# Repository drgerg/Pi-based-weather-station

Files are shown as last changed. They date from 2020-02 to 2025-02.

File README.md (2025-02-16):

# The Quest for a Reliable, Robust, Repairable Raspberry Pi-based Weather Station

**February, 2025 NOTE**: Over five years later, this weather station is still plugging away. There are occasional failures, but they are fixable.  That was the whole point.  I am **very** satisfied with this station as well as the home-brew front end I use to interact with it. It does exactly what it was designed to do. What more is there to say.

July 11, 2021 NOTE: I added a program flow-chart to the Station_Assembly_Docs folder that gives an overview of how the code parts fit together.

I just installed a DHT22 temperature and humidity sensor in WeatherPi. This sensor is more accurate than the BME280, apparently.  My experience so far proves this out.  I'm using the atmospheric pressure reading from the BME280, but now the temperature and humidity readings are coming from the DHT22.  The updated code is posted here today.

I was very pleased to see how well all the pieces and parts of WeatherPi are holding up.  Life outdoors can be brutal, but this little guy is doing well.

November 28, 2020 NOTE: The WeatherPi made it through Hurricane Sally and the rest of the hurricane season just fine.  It recorded over two feet of rainfall, and winds in excess of 75mph before the power went out and the battery eventually died.  I am very proud of the performance of the system and tickled pink that what has become the Pi-Net works so well.

Sept. 14, 2020 NOTE: The YuHan power supply died during a lightening storm.  I replaced it with the guts from a dead inexpensive UPS and a 120VAC to 12VDC supply. I replaced the UPS's dead battery with a fresh 5AH battery (which was twice the size of the original.)  If you're interested in this build, keep this in mind.  I'll get those details updated here as soon as I can. (new photos in PICS folder)

Project Initialized October 2019.
Project opened to public on Github February 2020. As built: c.$470.00.
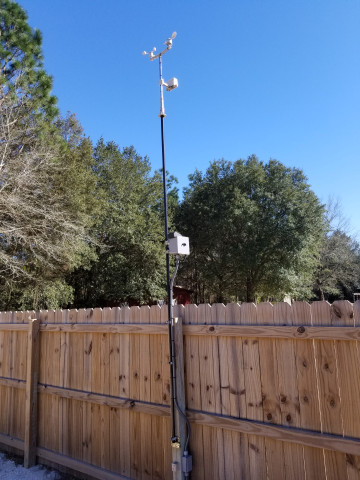
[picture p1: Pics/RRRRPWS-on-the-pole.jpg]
RRRRPWS on the pole.
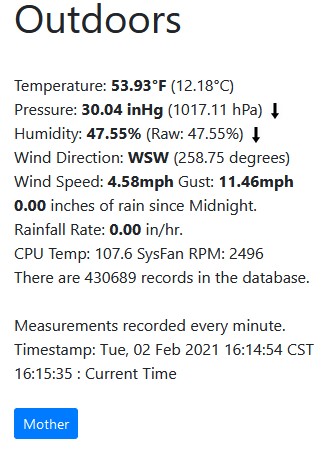
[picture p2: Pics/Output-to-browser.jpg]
Output as seen in browser.
  

My station is up and running.  It works.  I get good, accurate, stable readings for temperature, pressure, humidity, wind speed, wind direction and rainfall. I interact with my system by means of a web browser on my desktop or phone.

This project is not an easy one, but if I can build it, so can other people.

Here's what's where:

- **Code**: contains the Python3 code in the 'out' folder as well as the 'all' folder, which contains code for the mySQL server and browser front-end.  This folder also contains 'The_Code_is_what_it_is.md' which provides more detail on all that.
- **Component_Docs**: contains collected documentation for the various hardware pieces of the station.  The Station_Parts_List.pdf is there.
- **Pics**: contains pictures of the pieces and parts (640x480).  Contact me if you want higher resolution pics.
- **SKP_STL**: contains the Sketchup and stereolithography files for the 3D printed parts I designed for this project.
- **Station_Assembly_Docs**: contains documents pertaining to the actual assembly of the station.
  - **There are no step-by-step instructions there.**  But there is a [block diagram](./Station_Assembly_Docs/System_Block_Diagram.pdf) and a [schematic diagram](./Station_Assembly_Docs/WeatherPi_System_Schematic-V1.3.pdf).  And don't forget the Station_Parts_List.pdf in Component Docs.

This is not a quick-and-easy project.  The station is powered by a remote 12VDC power supply with a battery backup.  I dug a trench, put PVC conduit in it, and pulled 14AWG Romex into it.  It's a good solution.  I drove ground rods and put in-line lighting/surge protectors on both ends of that power run.  I use the guts from a low-cost UPS feeding a Buck converter for power.  By routing the 12V output of the converter through a relay (which is triggered by the PoolPi), I have a way to remotely power-cycle (reboot) the station.  This was VERY handy during development.

The whole Weather Station package is really two computers (and interfaces with two more the way I have it set up here).  The station acquires data from the sensors, makes necessary calculations and stores that data via WiFi to a mySQL server running in my house.  That machine also serves web interface data to end-users using Python/Flask/Jinja/Gunicorn and nginx (webserver).  Video from the Pi Camera gets sent to my Zoneminder system. That video **can** be viewed directly from the station using a web browser, but I already had Zoneminder going, so it just made sense to incorporate the feed from the WeatherPi.  The front-end server ("all" is its name) also displays the temperature and humidity in my shop.  That is gathered by another Pi with a DTH11 sensor on it.  It also writes to the mySQL database.

No guarantees are made. None. That is normal in projects such as this.

I have a pretty complete parts list and the aforementioned block diagram and wiring schematic available in the repo here.

### A bit of History

After throwing away my second Acurite weather station in only two years I decided I would build my own.  It may be cheaper to buy a more expensive commercial brand like Davis, but honestly, I'm sick of the throw-away culture when I can do something about it.

The goal of this project is to take advantage of the availability of the modular Pi and Arduino sensors and boards to create a weather station that I could repair when something died.  The Pi lives on the pole with the sensors, and communicates over WiFi.

The project is written in Python 3.

I don't try to make this system available to the Internet.  It is intended to be viewed and used locally, or by means of a VPN. I do upload data to [PWSWeather.com](https://www.pwsweather.com/station/pws/kflmilto35), which works really well.

I am making every attempt to provide enough documentation and schematics for anyone else to duplicate what I've done.

I am a self-taught coder, as anyone with experience can plainly see.  What I know is what I've done so far works here, and provides me with reliable and accurate data as compared to all the local commercial and government data sources.  

I use Visual Studio Code in Windows.  I use Microsoft's Remote-SSH extensions to work with my code on the WeatherPi out on the pole in the backyard.  The WeatherPi stores its data in a mySQL database running on another machine in the house. I use Filezilla to keep local copies of my code when I'm done editing and testing.

The system runs on a Pi 4 Model B.  Rather than re-invent the wheel on environmental sensors, I bought [Sparkfun's SEN-08942 Weather Meters](https://www.sparkfun.com/products/8942). I have a [DROK buck-converter](./Pics/DROK-Buck-Converter-mount.jpg) DC-to-DC power board, a real-time clock module, a analog-to-digital module, and a BME280 temperature, pressure, humidity sensor module all living in the box on the pole.  A Pi Camera v2 provides a 1280x720 view of the outdoor conditions.  

I own a Prusa MK3S 3D printer which I use to make mounts and other custom parts for assembling the whole thing.  Unlike many people who seem to think you can't use Sketchup for modeling for printing, I do it all the time with no problem.  The .skp and .stl files are here for you to use as you see fit.

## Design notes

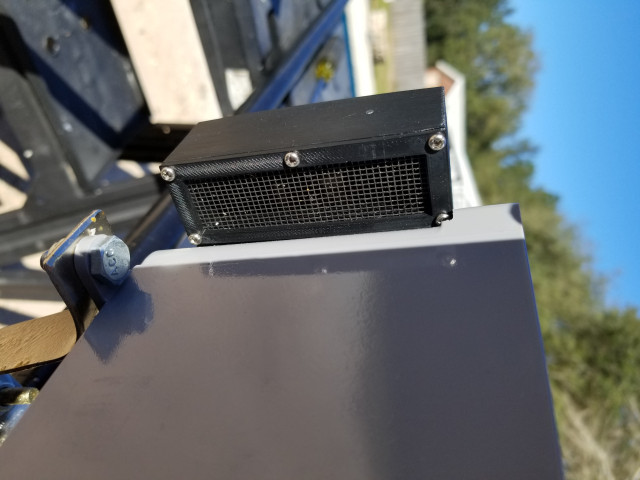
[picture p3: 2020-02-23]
Pics/air-chimney-output-vent.jpg

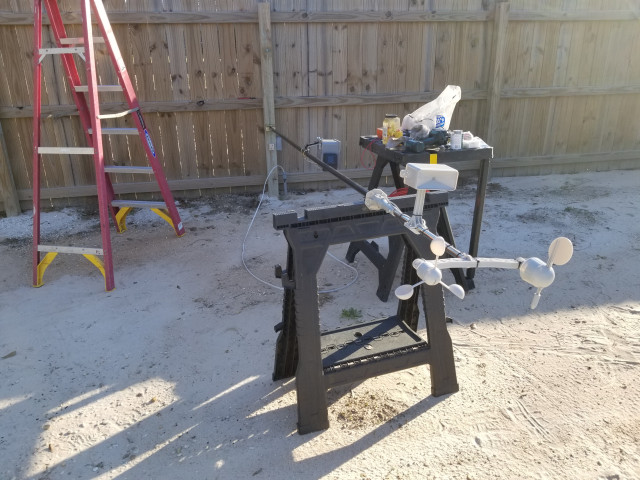
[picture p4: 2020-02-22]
Pics/RRRRPWS-service-mode.jpg

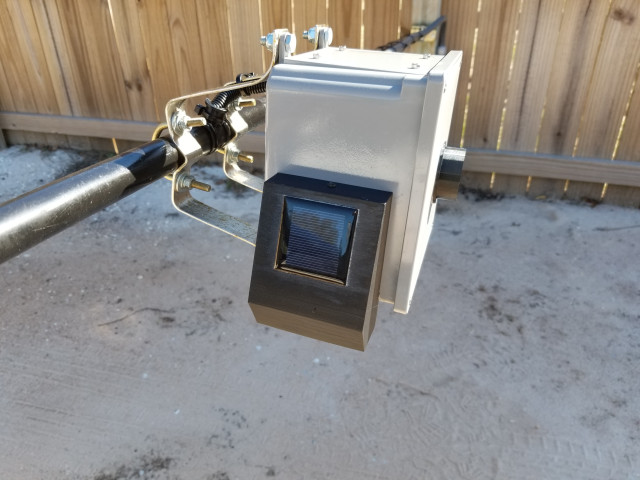
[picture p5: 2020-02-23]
Pics/RRRRPWS-top-view.jpg

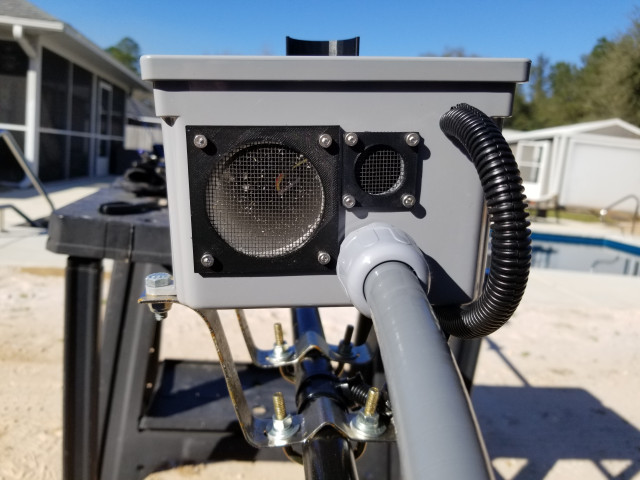
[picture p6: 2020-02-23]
Pics/RRRRPWS-bottom-view.jpg

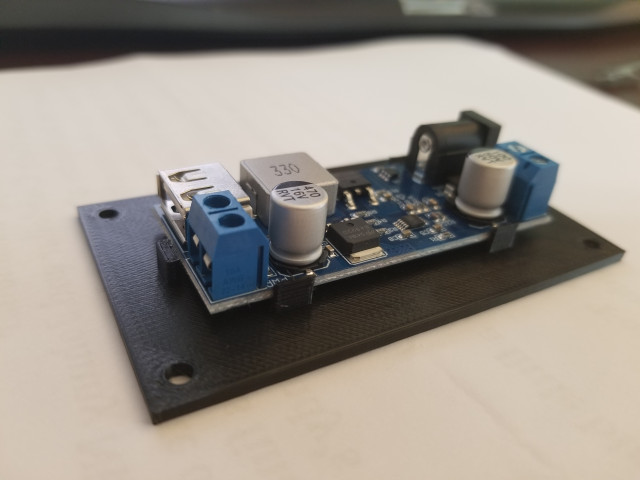
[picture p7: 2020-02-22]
Pics/DROK-Buck-Converter-mount.jpg

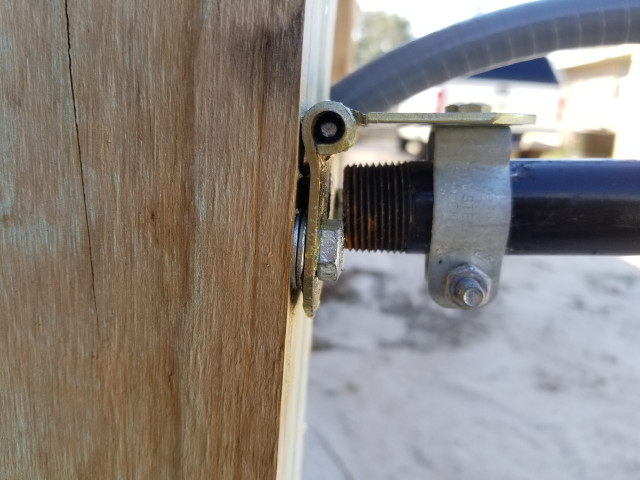
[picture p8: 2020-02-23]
Pics/bottom-mount-hinge.jpg

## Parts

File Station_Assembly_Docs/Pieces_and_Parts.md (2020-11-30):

# Pieces and Parts: Things you can get that make life easier

Getting the hardware part of this project together is not a trivial task.  I am hoping after a year of use I will be able to say it was worth it. (That's how long each of the two Accurite stations lasted.  Pathetic.)

**Be sure to look at the Station_Parts_List.pdf** located in the Component_Docs folder.  That's where I list the major parts that make up the weather station.

I have a carefully curated collection of odd things that make all of this easier.  I'm happy to share the list with you.  Most of it comes from Amazon.

* [EDGELEC 120pcs Breadboard Jumper Wires](https://www.amazon.com/gp/product/B07GD2BWPY/ref=ppx_yo_dt_b_asin_title_o05_s01?ie=UTF8&th=1) - These are made from copper wire, unlike some which are made from copper-coated aluminum.  If you ever need to clip off one end and solder it onto something (like I do frequently), you will be glad you got all copper.
* [Litorange 320PCS M2 Male Female Nylon Hex Spacer Standoff Screw Nut Assorted Assortment Kit (Black) ](https://www.amazon.com/gp/product/B07D78PFQL/ref=ppx_yo_dt_b_asin_title_o00_s00?ie=UTF8&psc=1) - I have two sizes of these standoffs, and they are wonderful.  Both of the kits I have contain multiple lengths of standoffs, screws, washers and nuts.  All nylon, and amazingly strong.
* [12v to 5v 5A Converter, DROK USB Buck Converter Voltage Regulator DC 9V-36V Step Down to DC 5V-5.3V 3.5-6A Volt Transformer Power Supply Module ](https://www.amazon.com/gp/product/B01NALDSJ0/ref=ppx_yo_dt_b_asin_title_o00_s00?ie=UTF8&psc=1) - I have about 5 of these guys now.  They are rock-solid and versatile.  They make me happy.
* [HVAZI 320pcs M2.5 Nylon Hex Spacer Standoffs Screws Nuts Assortment Kit; Male-Female(Black) ](https://www.amazon.com/gp/product/B06XKWDSPT/ref=ppx_yo_dt_b_asin_title_o03_s00?ie=UTF8&psc=1) - The other standoff kit.
* [18-8 Stainless Steel Flat Washer, Plain Finish, Meets DIN 9021, M3 Hole Size, 3.2mm ID, 9mm OD, 0.8mm Nominal Thickness (Pack of 100) ](https://www.amazon.com/gp/product/B009OK7GPO/ref=ppx_yo_dt_b_asin_title_o00_s00?ie=UTF8&psc=1) - Stainless Steel flat washers.  Part of the collection of Stainless Steel fasteners that I can't live without.
* [Honbay 100pcs 304 Stainless Steel M3 Square Nuts](https://www.amazon.com/gp/product/B06XPFLNBS/ref=ppx_yo_dt_b_asin_title_o08_s00?ie=UTF8&psc=1) - I learned the value of these square nuts when I assembled my Prusa MK3S kit.  More Stainless Steel fasteners.
* [iExcell 600 Pcs Metric M3 DIN912 Stainless Steel 304 Hex Socket Head Cap Screws Nuts Washers Hex Key Wrench Kit ](https://www.amazon.com/gp/product/B07J44YXV3/ref=ppx_yo_dt_b_asin_title_o08_s00?ie=UTF8&psc=1) - I use these a LOT for projects that have Arduino or Raspberry Pi parts.  The 3mm screws are used more on my custom mounts than anything else.  More of the Stainless Steel fastener collection.
* [HVAZI Metric M2.5 304 Stainless Steel Button Head Socket Cap Screws Nuts Assortment Kit](https://www.amazon.com/gp/product/B076ZN18KZ/ref=ppx_yo_dt_b_asin_title_o08_s00?ie=UTF8&psc=1) - The Raspberry Pi has mounting hole in its PCB that accept these 2.5mm screws.  More of the Stainless Steel fastener collection.
* [CHENBO 620pcs 2.54mm/0.1" Connectors Wire Jumper Cable Pin Header Connector Crimp Pins Kit](https://www.amazon.com/gp/product/B077X8XV2J/ref=ppx_yo_dt_b_asin_title_o03_s00?ie=UTF8&psc=1) - Pins, Sockets, and plastic connector bodies of various pin-counts.  Use the tool below to crimp these pins.
* [IWISS Open Barrel Terminal Crimper Plier Tool for Molex Style DELPHI AMP TYCO Terminals Crimper Open Barrel 24-14 AWG](https://www.amazon.com/gp/product/B07476C1LD/ref=ppx_yo_dt_b_asin_title_o04_s00?ie=UTF8&psc=1) - This is a pretty good tool. What I mean by that is, you can crimp Molex and other open-barrel pins with it, including DuPont pins and sockets, which is what we use with the Pi and such. The tool works adequately, and is cheap. A better quality tool like this is way more expensive. You will have to learn how to get good results with this (or any) tool. It is not intuitive, but it can be done, and once done, it's as good as a million dollar crimp.
* [IWISS SN-28B Crimping Tool for AWG28-18 Dupont Pins](https://www.amazon.com/IWISS-Professional-Compression-Ratcheting-Wire-electrode/dp/B00OMM4YUY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) - This is a tool I just discovered that is not very expensive and will deliver a better quality crimp.  I say that based on decades of crimping all sorts of connectors.  I may be buying this tool for my own bench.

I listed these parts because having a stock of this stuff saves me a lot of time and results in a finished product that works well and one I'm not ashamed to show people.  If you can afford to do so, I highly recommend you stock your hobby locker with these sorts of parts and pieces.

* [5VDC 4-wire cooling fan](https://www.amazon.com/BSB05505HP-BASA5508R5H-0-40A-5-5-Cooling/dp/B01JEDTE5K) - The cooling fan I used was one I had scavenged from a dead laptop.  As of 4/28/20 this fan, which is similar but not exactly the same, is available for $14 at Amazon. It is a replacement fan for a Lenovo NUC or laptop.  I'm putting this in here just to give anyone who cares a place to start.

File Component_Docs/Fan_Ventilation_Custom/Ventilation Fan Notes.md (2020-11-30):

### Ventilation Fan Notes

There is an occasional need for additional ventilation other than that provided by natural convection.

I used a small 5V fan I had scavenged from a laptop some years ago.  It is a 4-wire fan, which means it has a speed sensor, and can be controlled by a PWM output on the Pi.

This [replacement fan from Amazon](https://www.amazon.com/Tested-Replacement-Cooling-Inspiron-CN-031TPT/dp/B07J4LFRYX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) should be a drop-in replacement for the fan I used. 

I printed custom mounting parts for this fan.  This means anyone else building this project will need to figure out how they're going to mount whatever fan they have to use for this particular application.

I could not find any documentation for the specific fan I had, but I did find a similar fan by the same manufacturer and have included the spec sheet on it here.

The sketch in the .jpg file comes from a YouTube video and was helpful in sorting out how to use the 4-wire fan in my project.

The final working wiring diagram is incorporated into the main schematic for the station.

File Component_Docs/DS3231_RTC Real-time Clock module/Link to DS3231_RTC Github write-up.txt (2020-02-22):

http://www.intellamech.com/RaspberryPi-projects/rpi_RTCds3231

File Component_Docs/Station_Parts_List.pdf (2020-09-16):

Printed for Ledger paper | 11"x17" Landscape | Gregory A. Sanders, 2020
| | (#) means see Notes below | | | | | | $463.11
Category | Name | Purpose | Description | Make | Model | Qty | Cost | Extended | Vendor | SubstitutionOK?
Mounting | Pole | Main mount pole | LDR 3/4-in x 10-ft 150-PSI Black Iron Pipe | LDR | 314 34X120 | 1 | 20.79 | 20.79 | Lowes | yes
Mounting | Clamps - pole | hold pole to post | Sigma Electric ProConnex 3/4-in Conduit Hangers | Sigma | 49110 | 3 | 0.68 | 2.04 | Lowes | yes
Mounting | Paint | paint for black iron pole | Rust-Oleum Stops Rust Gloss Black Spray Paint | Rust-Oleum | 295387 | 1 | 3.97 | 3.97 | Lowes | yes, carefully
Mounting | Naptha (Paint Cleaner/thinner) | to clean black pipe for painting | Jasco 32-fl oz Fast to Dissolve Naphtha | Jasco | QJVM194 | 1 | 8.98 | 8.98 | Lowes | Naptha is best. Mineral spirits will do, but . . .
Mounting | PVC segment | transition from sensors to pipe (1) | See Note 1 | | | | | 0.00
Mounting | Hinge | allows pole to tilt down for service | Gatehouse 3-1/2-in Satin Nickel 5/8-in Radius Mortise Door Hinge | Gatehouse | S841-509 | 1 | 3.08 | 3.08 | Lowes | yes. any door hinge will be fine.
Mounting | Brackets | holds box on pole | RCA VH125R 4" Antenna Wall Mount Kit, 2 pk | RCA | VH125R | 1 | 5.98 | 5.98 | Lowes | yes, if distance between holes matches box
Housing | Box | Houses electrical components | 6 in. x 6 in. x 4 in. Gray PVC Junction Box | Carlon | E987RR | 1 | 13.94 | 13.94 | Home Depot | yes, but must be “weatherproof”
Housing | Box | houses pole-end lightning arrestor | 1-Gang Non-Metallic Weatherproof Gray Box with Three 1/2 in. or 3/4 in. Outlets Bell | | PSB37550GYB | 1 | 5.87 | 5.87 | Home Depot | yes, but must be “weatherproof”
Housing | Box | houses 120VAC to 12VDC supply | Electronic Equipment Enclosure Box, 12" x 12" x 4", Non-Metallic, 1-Pack | | EB1212-1 | 1 | 30.33 | 30.33 | Amazon | yes
Electrical | Liquid-tight conduit (2) | Conduit | Southwire Ultratite Non-Metal Liquid-tight 25-ft | Southwire | 55094251 | 1 | 11.44 | 11.44 | Lowes | yes See Note (2).
Electrical | Liquid-tight connector | connects conduit to boxes | Southwire 1/2-in Screw-in Connector Conduit Fitting | Southwire | 58133601 | 6 | 2.34 | 14.04 | Lowes | yes
Electrical | 14 AWG power wire | carries 12VDC from supply to pole | 250 ft. 14/2 Solid Romex SIMpull CU NM-B W/G Wire | Southwire | 28827455 | 1 | 37.89 | 37.89 | Home Depot | yes. Length depends on your installation
Electrical | Power Supply w/ Battery BU | supplies 12VDC to station (3) | Power Supply for System AC 110-240V to DC 12V 5A | YuHan | 6.07128E+11 | 1 | 29.99 | 29.99 | Amazon | Yes. I currently use guts from an old UPS.
Electrical | Battery | used as a standby power source | 12V 5Ah Home Alarm Battery with F1 Terminals | Expert Power | EXP1250 | 1 | 15.99 | 15.99 | Amazon | Yes. 7ah provides longer run during outage.
Electrical | Cord | connect pwr supply to AC | 14 AWG 3 Conductor 10 ft Replacement Power Cord, Pigtail | Middleway | B07Q9KV5MF | 1 | 17.99 | 17.99 | Amazon | Yes.
Electronic | Raspberry Pi | main computer for station | Pi 4 Model B, BCM2711 SoC, 2GB DDR4 RAM, USB 3.0, PoE Enabled Raspberry Pi | | RPI4-MODBP-2GB | 1 | 35.00 | 35.00 | Newark | Sure? I thought about using a Zero W.
Electronic | DROK Buck Converter | 12VDC to 5VDC power module | Voltage Regulator DC 9V-36V Step Down to DC 5.3V 3.5-6A | DROK | 200217 | 1 | 9.99 | 9.99 | Amazon | Substitution not recommended, but possible.
Electronic | Raindrop sensor | Raindrop sensor | LM393 Rain Drops Sensor | HiLetgo | 3-01-0312-A | 1 | 4.49 | 4.49 | Amazon | Yes. Not required for station to function.
Electronic | Main Sensor 1 | Temp, Humidity, Pressure | BME280 Humidity Temperature Pressure Sensor with I2C | DIYmall | BC26852 | 1 | 9.49 | 9.49 | Amazon | No.
Electronic | Main Sensors 2 | Wind speed, direction, Rainfall | Weather Meters | Sparkfun | SEN-08942 | 1 | 76.95 | 76.95 | Sparkfun | Yes. Updated version is available from Sparkfun.
Electronic | Variable speed system fan | provides air flow and cooling (4) | 4-Wire 4-Pin CPU Cooling Fan for Dell Inspiron 13 5000 | BAY Direct | CN-031TPT | 1 | 16.99 | 16.99 | Amazon | Yes. I used a pull from a dead Dell 13-7378 laptop
Electronic | Lightning Arrestor (qty 2) | surge protector for 12VDC power | LRSO1 DC 12V Lightning Arrester | Uxcell | LRS01-DC12V | 2 | 13.68 | 27.36 | Amazon | Yes. Use your own judgment here.
Electronic | USB power cable | From Buck Converter to Pi | Right Angle USB Type C to USB A (1.5ft) | UGreen | 20855 | 1 | 6.99 | 6.99 | Amazon | Yes. 90 degree connectors are important.
Electronic | Realtime clock | Keeps station time accurate | DS3231 Precision RTC Breakout [ADA3013] | Adafruit | 8541582433 | 1 | 19.95 | 19.95 | Amazon | No.
Electronic | Analog to digital converter | Wind direction values | ADS1115 16 Bit 16 Byte 4 Channel I2C IIC Analog-to-Digital ADC | HiLetgo | B01DLHKMO2 | 1 | 6.99 | 6.99 | Amazon | No.
Electronic | Raspberry Pi camera module | Monitor outdoor conditions | Raspberry Pi Camera V2 Module IMX219 8-megapixel Sensor | Raspberry Pi | V2.0-US | 1 | 26.59 | 26.59 | Amazon | Yes.
| | | | | | | | 0.00
| | | | | | | | 0.00

# NOTES:

| (1) You can see this part in the photos. It is the plastic piece just below the sensors’ chrome mount tube. This PVC piece serves two purposes, it electrically isolates the sensors from the pole, and it holds them firmly in place. I used a part from one of the two failed Acurite stations we had. You need something that can firmly hold the larger black iron pipe pole, and the smaller chromed tube that comes with the Sparkfun Sensors. There are a multitude of ways to accomplish this.
| (2) The actual number of conduit parts is completely dependent on how far your power supply is from the weather station.
| (3) This power supply was chosen because it is capable of functioning as a battery backup in case of power failure, and has an on-board remote controllable relay. Both features are important to this build.
| (4) This fan pulls air up into the chimney which serves two functions:

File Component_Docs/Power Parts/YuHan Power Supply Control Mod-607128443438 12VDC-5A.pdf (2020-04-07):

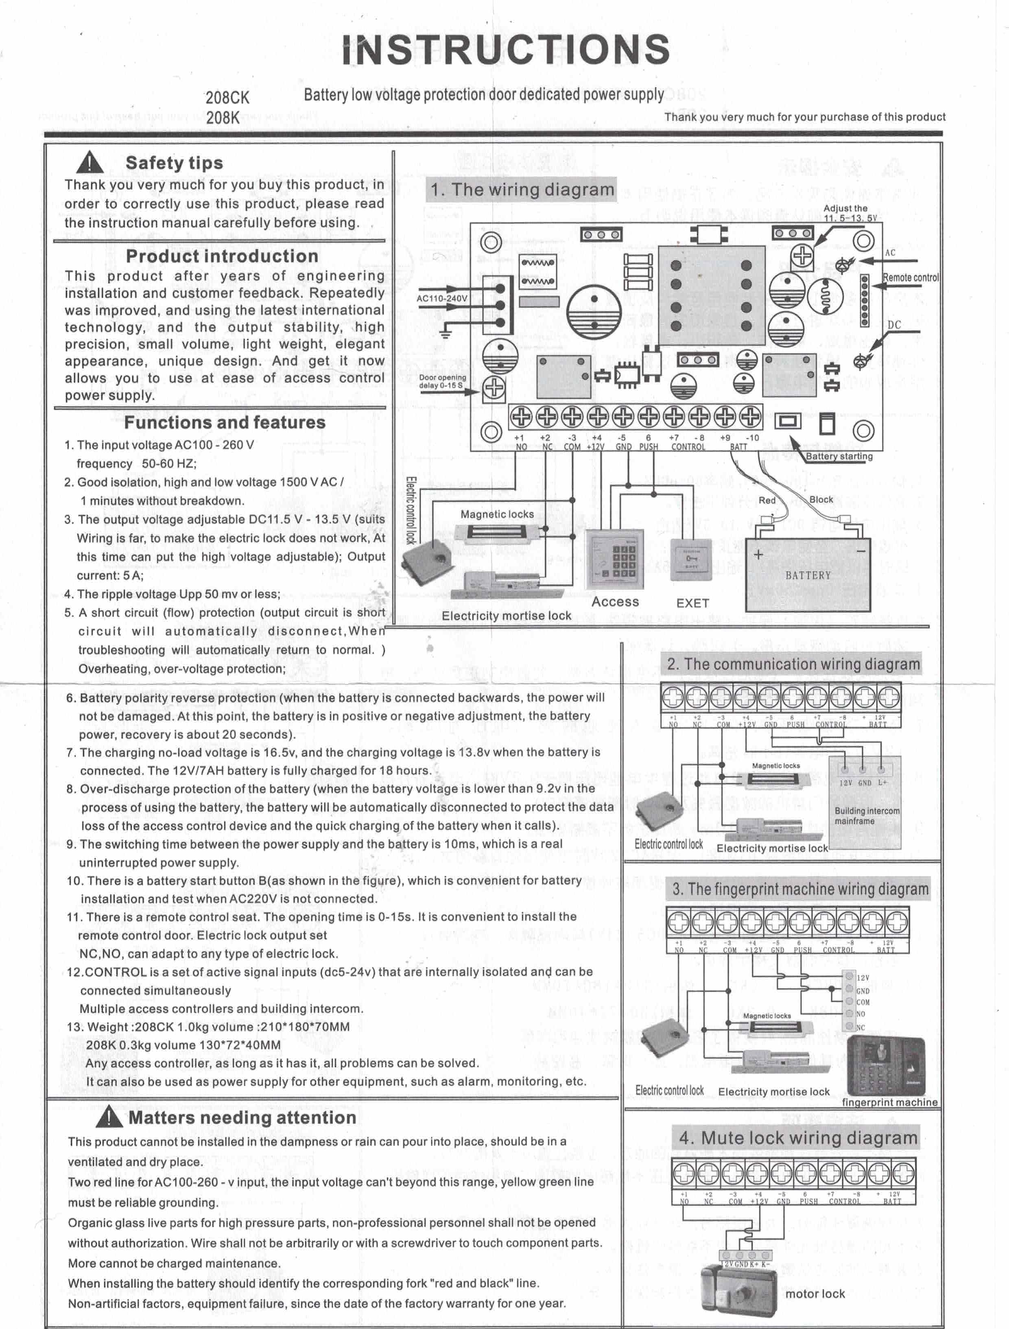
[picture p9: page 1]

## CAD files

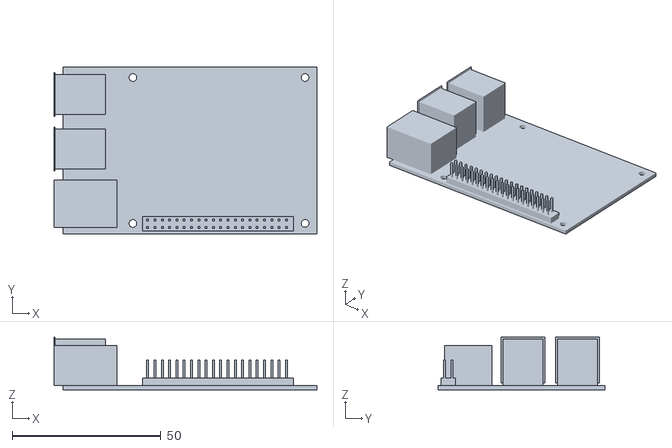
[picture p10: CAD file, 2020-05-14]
SKP_STL/Pi 4 Model.stl
88.3 x 56.0 x 17.7

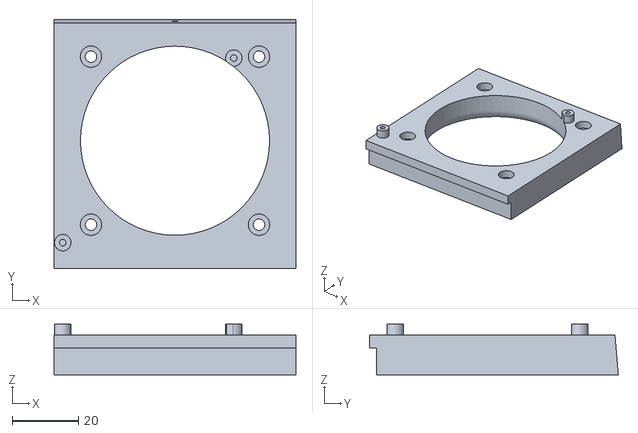
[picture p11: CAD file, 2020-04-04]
SKP_STL/FanMountV4.stl
73.2 x 75.2 x 15.3

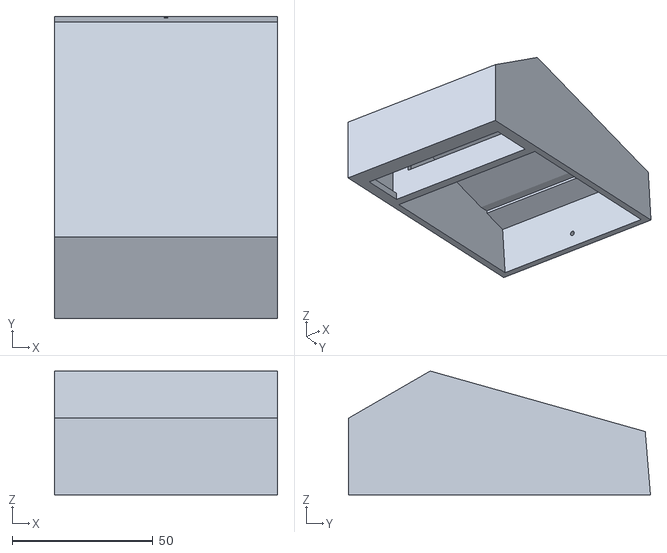
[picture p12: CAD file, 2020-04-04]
SKP_STL/ShroudV4b.stl
79.2 x 107.1 x 44.0

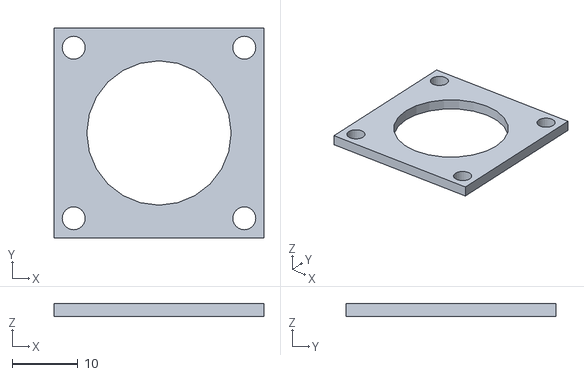
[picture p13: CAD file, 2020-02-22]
SKP_STL/Screen Holder-small.stl
32.0 x 32.0 x 2.00

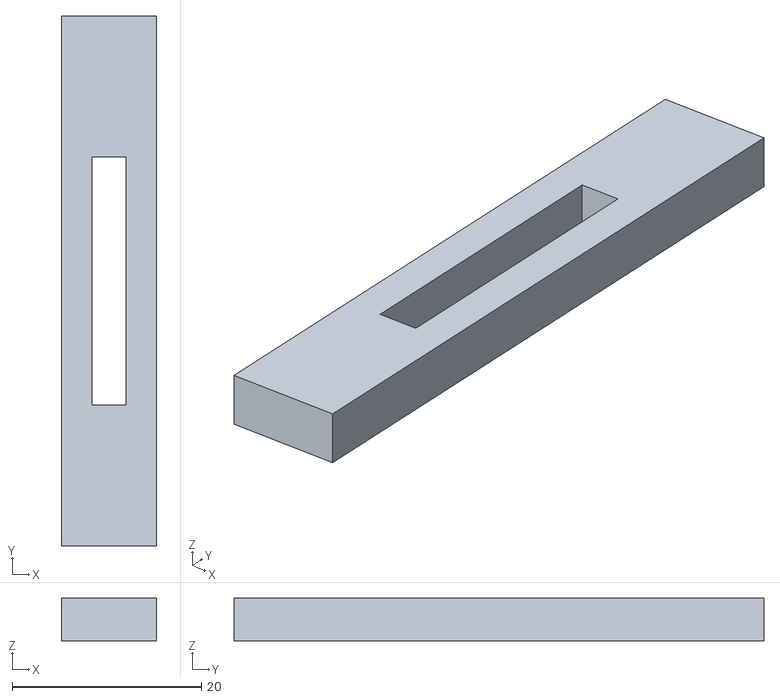
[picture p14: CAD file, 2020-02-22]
SKP_STL/10-pin-header-holder_insert.stl
10.0 x 56.0 x 4.50

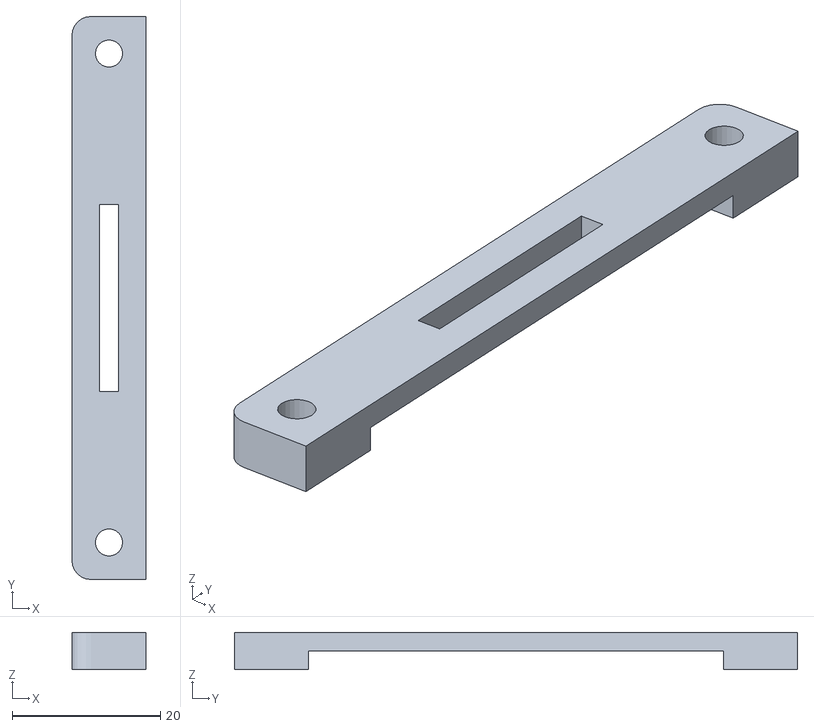
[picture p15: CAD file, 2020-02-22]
SKP_STL/10-pin-header-holder.stl
10.0 x 76.0 x 5.00

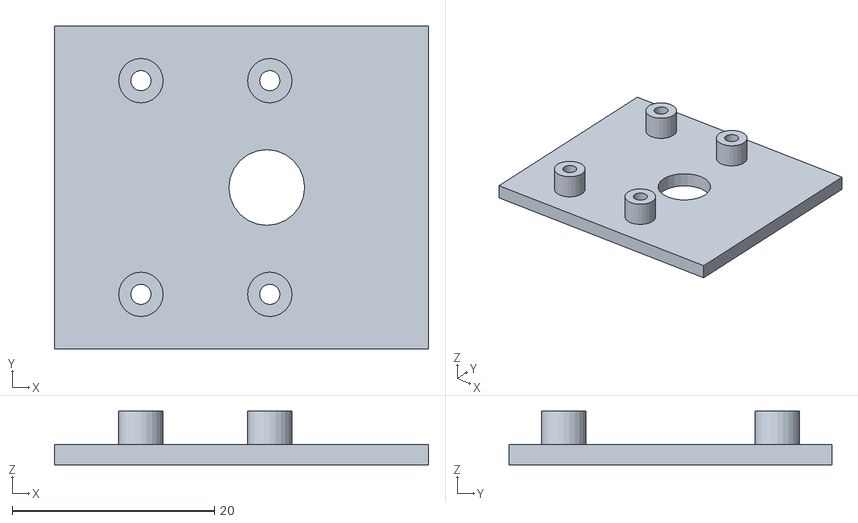
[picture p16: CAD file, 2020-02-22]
SKP_STL/Pi Camera 2 mount.stl
37.0 x 32.0 x 5.31

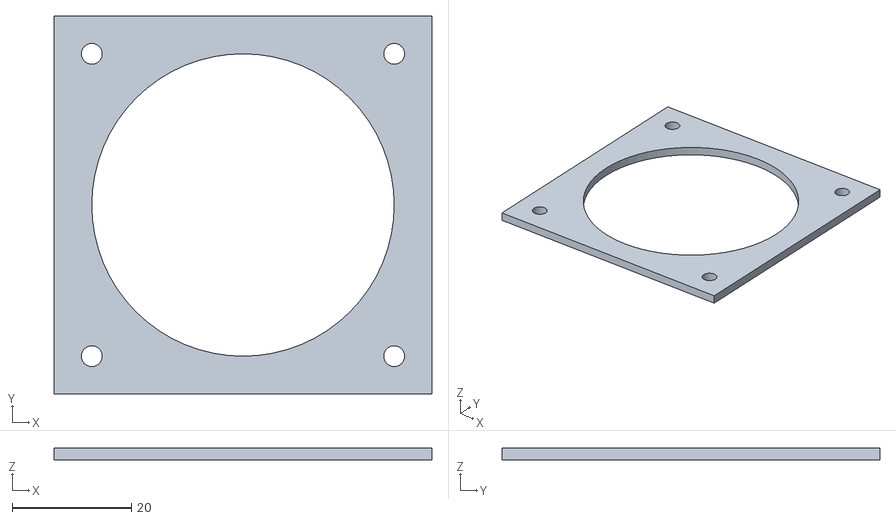
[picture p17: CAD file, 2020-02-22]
SKP_STL/Screen Holder.stl
63.5 x 63.5 x 2.01

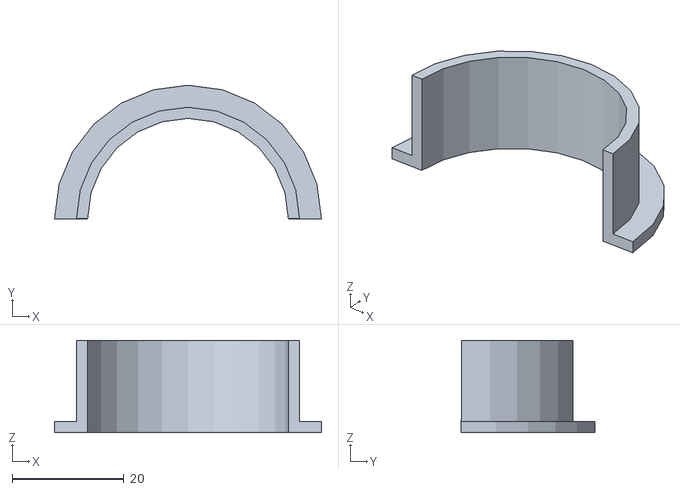
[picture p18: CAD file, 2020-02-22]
SKP_STL/Lens Shade.stl
47.9 x 23.9 x 16.5

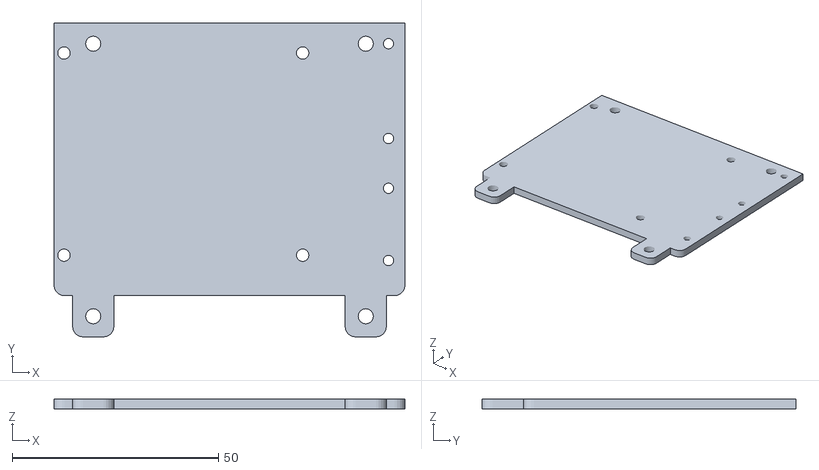
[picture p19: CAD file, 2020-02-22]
SKP_STL/Mount_Pi_RTC_ADC.stl
85.0 x 76.0 x 2.51

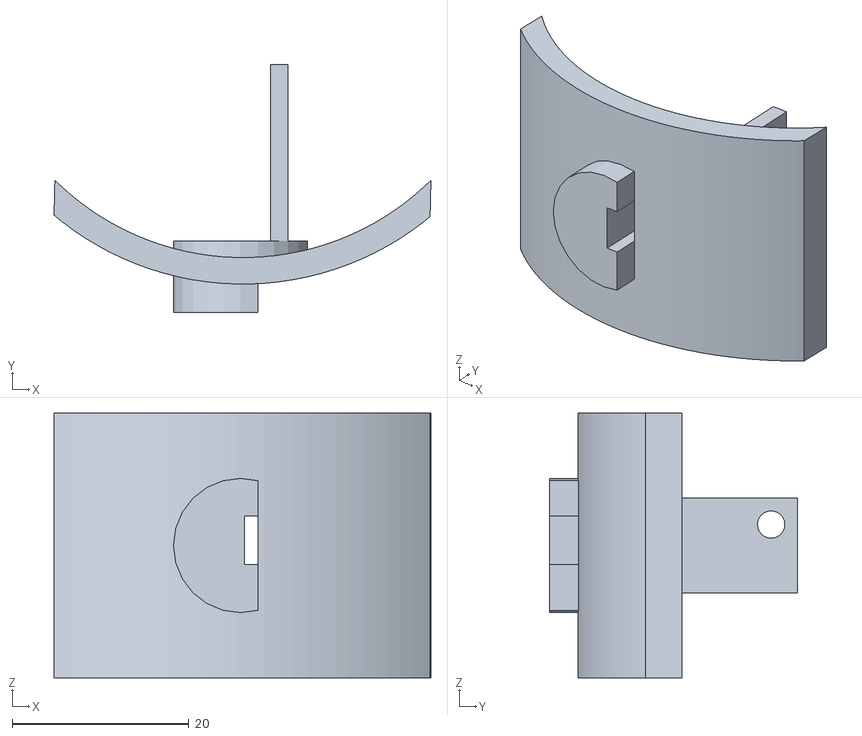
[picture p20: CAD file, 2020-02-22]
SKP_STL/BME280_holder.stl
42.7 x 28.1 x 30.0

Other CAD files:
SKP_STL/10-pin-header-holder.skp
SKP_STL/10-pin-header-holder_insert.skp
SKP_STL/BME280_holder.skp
SKP_STL/FanMountV4.skp
SKP_STL/Lens Shade.skp
SKP_STL/Mount_Pi_RTC_ADC.skp
SKP_STL/Pi 4 Model.skp
SKP_STL/Pi Camera 2 mount.skp
SKP_STL/Screen Holder-small.skp
SKP_STL/Screen Holder.skp
SKP_STL/ShroudV4b.skp

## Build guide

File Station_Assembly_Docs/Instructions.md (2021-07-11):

# Instructions (No one apparently cares, and that's OK)

Turn off power save mode on the Pi's built-in Wifi radio.  You can see the status of this mode with:

`sudo iw wlan0 get power_save`

Turn it off with:

`sudo iw wlan0 set power_save off`

I'll post something here about making that permanent in the future.

UPDATE: It's been two years, and I still haven't posted anything here about making that setting permanent.  But I thought about it.

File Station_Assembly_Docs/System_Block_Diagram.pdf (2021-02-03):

# ArrrrPWS

Overall System Block Diagram - (c)2020 by Gregory Allen Sanders. GPL v3.0

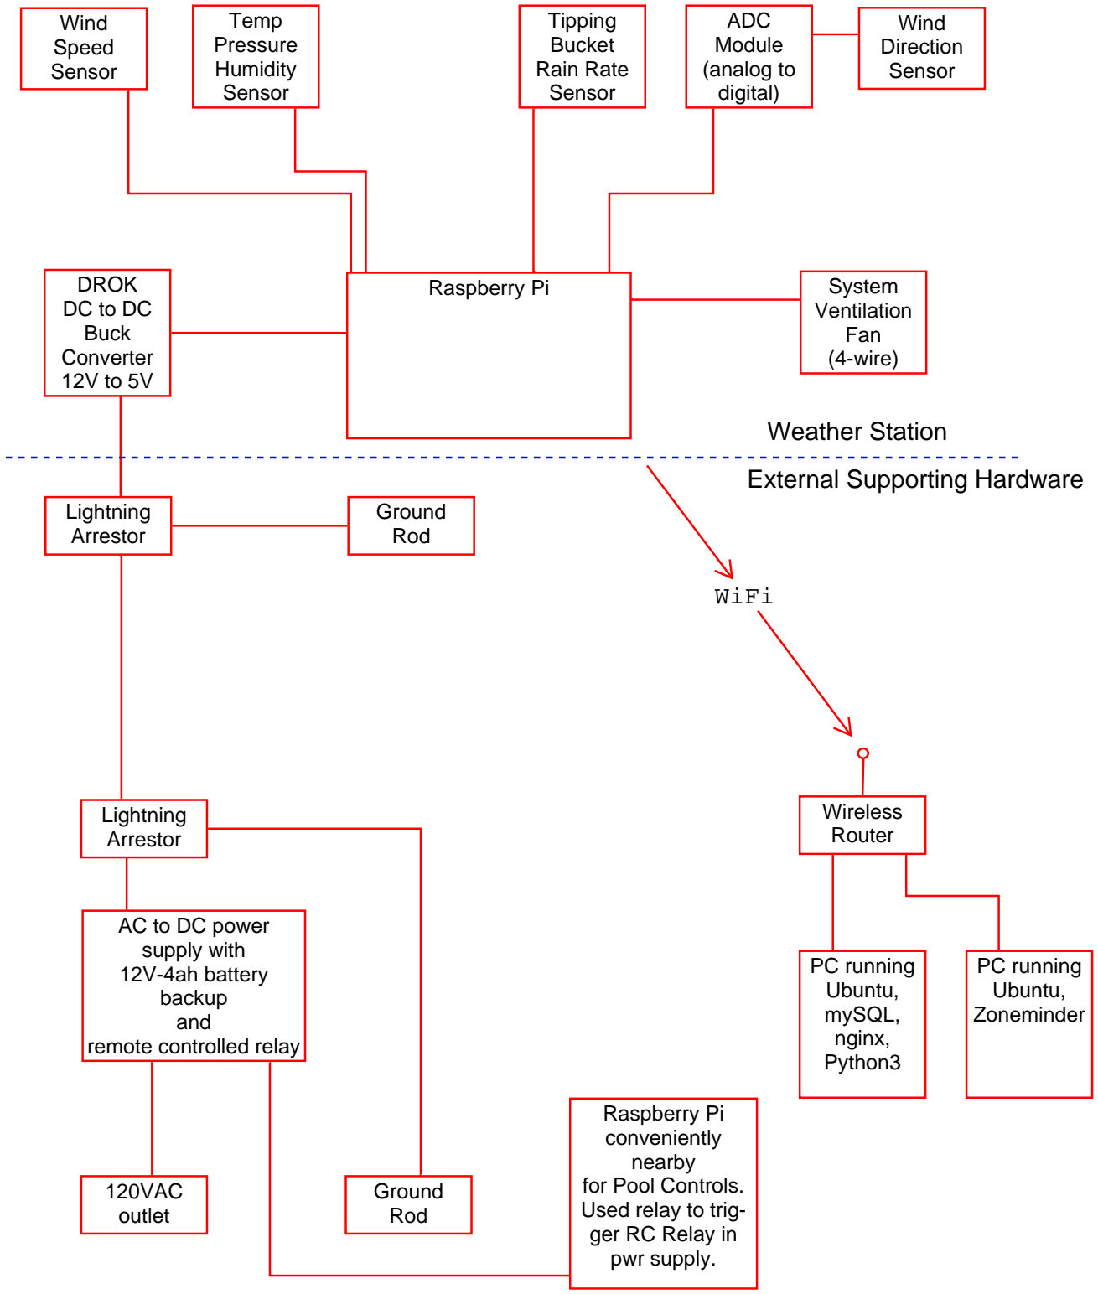
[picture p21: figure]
Weather Station; External Supporting Hardware; Wind Speed Sensor; Temp Pressure Humidity Sensor; Tipping Bucket Rain Rate Sensor; DROK; Raspberry Pi; DC to DC Buck Converter 12V to 5V; AC to DC power supply with 12V-4ah battery backup and remote controlled relay; 120VAC outlet; System Ventilation Fan (4-wire); Lightning Arrestor; Ground Rod; PC running Ubuntu, mySQL, nginx,; Python3 Wireless Router; PC running Ubuntu, Zoneminder; WiFi; ADC Module (analog to digital); Wind Direction Sensor; Raspberry Pi conveniently nearby for Pool Controls. Used relay to trig- ger RC Relay in pwr supply.

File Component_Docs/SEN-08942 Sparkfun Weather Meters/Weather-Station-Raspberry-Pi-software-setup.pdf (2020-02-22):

## Weather Station Raspberry Pi Software Setup

By David W. Enström
This personal weather station uses the SparkFun weather sensors
(Argent Data Systems), and the BC Robotics add-on hardware (HAT) to interface these sensors to the Raspberry Pi.

See: https://www.sparkfun.com/products/8942 and https://www.bc-robotics.com/tutorials/raspberry-pi-weather-station-part-1/ (https://www.bc-robotics.com/tutorials/raspberry-pi-weather-station-part-1/)

The weather station monitors (and optionally shares the data with Wunderground):

- Wind Speed – in km/h
- Wind Direction – in degrees
- Rainfall – in mm
- rainRate – in mm/hr
- Temperature – in degrees C
- Air Pressure – in hecto Pascals
- Humidity – in percent

Instructions for constructing this weather station and all the required

components are in the “Weather- Station-Raspberry-Pi-

construction.pdf” PDF file.
Raspberry Pi

The weather station is connected to a Raspberry Pi … it is actually a HAT (Hardware Attached on Top). The HAT is from BC Robotics and uses the BME280 temperature, pressure, and humidity sensor, the
DS18B20 Digital temperature sensor, and the SparkFun Weather
sensors from Argent Data Systems for wind and rain.

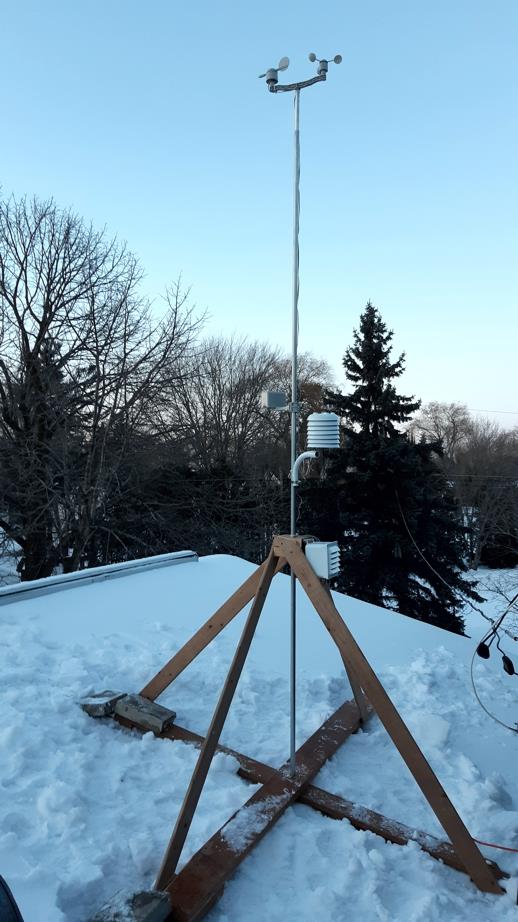
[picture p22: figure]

The Raspberry Pi is setup with a static IP, to connect to and manage the Pi easier, for example:

192.168.0.110/24

Do this by editing the following file:

etc/dhcpcd.conf

Command Summary
Install the vsftpd FTP service (in Preferences / Add/Remove Software) and to enable FTP write access to the Pi; edit vsftpd.conf and:

write_enable=YES

To edit a system file in Raspbian: sudo leafpad filename

To shutdown the Pi: sudo shutdown -h now

To start/stop WeeWX:

sudo /etc/init.d/weewx start

sudo /etc/init.d/weewx stop

Setup Raspbian for WeeWX and the BC Robotics Hardware

The following assumes that you already have Raspbian running on your Pi. See: https://www.bcrobotics.com/tutorials/raspberry-pi-weather-station-part-2/ (https://www.bc-robotics.com/tutorials/raspberry-pi-weather-station-part-2/) for basic Raspbian setup instructions.

Before installing WeeWX and the BC Robotics driver, setup the required software by running the following commands (in this order) from the command prompt:

Install the Adafruit Python GPIO Library

sudo apt-get update

sudo apt-get install build-essential python-pip python-dev python-smbus git

git clone https://github.com/adafruit/Adafruit_Python_GPIO.git

cd Adafruit_Python_GPIO

sudo python setup.py install

Install the Adafruit BME280 Library

cd

git clone https://github.com/adafruit/Adafruit_Python_BME280.git

cd Adafruit_Python_BME280

sudo python setup.py install

Test the BME280 Sensor if desired

python Adafruit_BME280_Example.py

Install the ADS1x15 Library, the ADS1015 Analog to Digital chip (wind direction)

cd

git clone https://github.com/adafruit/Adafruit_Python_ADS1x15.git

cd Adafruit_Python_ADS1x15

sudo python setup.py install

Setup the DS18B20 temperature sensor and install the software library

cd

sudo modprobe w1-gpio

sudo modprobe w1-therm

cd /sys/bus/w1/devices

ls

cd

sudo apt-get install python-w1thermsensor

The “ls” command will display the contents of the devices “folder” in the window. The DS18B20 shows up as an address something like “28-0316853d8fff” – but each sensor has a unique ID.

You can test the sensors by running the included test app: BCRobotics-test-app.py

Run the Python IDE:

>>idle
Now open the “BCRobotics-test-app.py” test app from the IDE and hit 'F5' to run it. It will continuously print out the readings from the sensors, including the value read from the ADC for the wind direction. Use these values (and a test template for the wind direction) to double check the values used in the driver. Hit “<ctrl> c” to stop the program.

WeeWX Setup

The Raspberry Pi runs WeeWX, a freely available weather application written in Python. The installation of WeeWX (see: http://weewx.com/docs/debian.htm) results in the following layout:

Role | Symbolic Name | Location
WeeWX Root | WEEWX_ROOT | /
Executables | BIN_ROOT | /usr/bin/weewxd
Configuration file | CONFIG_ROOT | /etc/weewx/weewx.conf
Skins and templates | SKIN_ROOT | /etc/weewx/skins
SQLite databases | SQLITE_ROOT | /var/lib/weewx/
Web pages and images | HTML_ROOT | /var/www/html/weewx/
Documentation | DOC_ROOT | /usr/share/doc/weewx/
Examples | EXAMPLE_ROOT | /usr/share/doc/weewx/examples/
Log files | | /var/log/syslog
PID File | | /var/run/weewx.pid
Utilities | | /usr/share/wee_*
Extensions (i.e., the driver) | | /usr/share/weewx/user/

WeeWX logs many events to the system log. On Debian systems, this is /var/log/syslog. BCRobotics Driver Installation

Edit the [Station] section in weewx.conf to add the following parameters, adjusted for your particular situation:

- location = short description (e.g., Honey Gables, a suburb of Ottawa, Canada)
- latitude = 45.38044
- | longitude = | -75.29585
- altitude = 87 meters
- station_type = BCRobotics
- station_url = http://www.mywebsite.com
- units = metric
- week_start = 0

The values in bold are mandatory definitions for the BCRobotics driver.

Once this setup is done, download the BCRobotics driver TAR file to your Raspberry Pi from here:

wget -O BCRobotics.zip https://github.com/David-Enst/WeeWX-BCRobotics/archive/master.zip
Install the Extension Tar file (copied to /home/pi/) with an optional “dry run”:

sudo wee_extension --install=/home/pi/BCRobotics.zip (--dry-run)
The wee_device utility can be tried, but has not been tested. It is used to configure BCRobotics stations, including updating various weewx.conf parameters. This can also be done manually by defining the following parameters in weewx.conf.

Definition of the BCRobotics driver:

[BCRobotics]
# This defines the "Spark Fun" SEN-08942 / BC Robotics weather stations.

# See: | https://www.sparkfun.com/products/8942

# | https://www.bc-robotics.com/tutorials/raspberry-pi-weather-station-part-1/

# The time (in seconds) between LOOP packets.

loop_interval = 3

# Driver mode - tcp, udp, or serial

mode = serial

# If serial, specify the serial port device. (ex. /dev/ttyS0, /dev/ttyUSB0, # or /dev/cuaU0)

# If TCP, specify the IP address and port number. (ex. 192.168.36.25:3000) port = /dev/ttyS0

# The amount of time, in seconds, before the connection fails if

# there is no response

timeout = 3

# Debug level - the level of message logging. The higher # the number, the more info is logged.

debug_read = 0

# The driver to use:

driver = user.BCRobotics

Definition of [[[Units]]] to ensure the web pages generated display the correct units:

[[StandardReport]]
# The StandardReport uses the 'Standard' skin, which contains the # images, templates and plots for the report.

skin = Standard

[[[Units]]]
[[[[Groups]]]]
group_altitude = meter
group_speed2 = km_per_hour2 group_pressure = hPa
group_rain = mm
group_rainrate = mm_per_hour group_temperature = degree_C group_degree_day = degree_C_day group_speed = km_per_hour

The database and driver is setup to store values in METRIC by default. Therefore, the following update to the quality control parameters are required:

[StdQC]

[[MinMax]]
barometer = 800, 1110, mbar # = hPa pressure = 800, 1110, mbar # = hPa

outTemp = -50, 49, degree_C inTemp = -40, 49, degree_C outHumidity = 0, 100
inHumidity = 0, 100
windSpeed = 0, 300, km_per_hour

The [StdConvert] section is updated to reflect the fact that all data in the database is stored in METRIC by default:

target_unit = METRIC | # Options are 'US', 'METRICWX', or 'METRIC'

Finally, the archive section is updated to force WeeWX to generate archive records through software generation, since the BC Robotics setup does not generate them:

[StdArchive]
# If possible, new archive records are downloaded from the station

# hardware. If the hardware does not support this, then new archive # records will be generated in software.

# Set the following to "software" to force software record generation. record_generation = software

Most of these parameters should be setup during the driver installation, but they should all be verified.

Station data
The following table shows the data provided by the station hardware and those calculated by WeeWX.

BCRobotics Station Data

Database Field | Observation | Loop | Archive
dateTime | - | D
usUnits | - | D
interval | - | D
barometer | | S
pressure | pressure | H
altimeter | | S
inTemp (Case) | case_temp | H
outTemp | outTemp | H
outHumidity | outHumidity | H
windSpeed | windSpeed | H
windDir | windDir | H
rain | rain | D
rainRate | rainRate | D
rainTotal | - | S
dewpoint | - | S
windchill | - | S
heatindex | - | S

H indicates data provided by Hardware
D indicates data calculated by the Driver
S indicates data calculated by the StdWXCalculate Service

Some references:

https://www.bc-robotics.com/tutorials/raspberry-pi-weather-station-part-2/

http://www.weewx.com/docs/usersguide.htm#about

https://docs.python.org/2.7/contents.html

https://www.lenntech.com/calculators/humidity/relative-humidity.htm

https://sourceforge.net/p/raspberry-gpio-python/wiki/Inputs/

https://github.com/David-Enst/WeeWX-BCRobotics

## Weather Formulæ

Wind Direction

The wind direction sensor outputs a different number read by an ADC (analog-to-digital converter) based upon the direction—but this number will change a small amount based on temperature, power fluctuations, and the actual resistors in the sensor. so you can’t just check if the ADC output matches a number in a list. Instead, they fall within a range as shown in the table.

Actual readings from my sensor, used to fine-tune the Python code in the driver, are shown below. Note that in the BCRobotics.py driver the following selections are used to try to cover all possible values. This eliminates an out-of-range error, and therefore a faulty wind direction (or program crash!). It is quite likely that the driver will work properly with the range selection values shown, but it doesn’t hurt to do a little test to see the actual values from your device. The numbers are found by manually moving the wind direction sensor to each of the 16 directions and reading the output. Write these numbers down. A compass rose template is provided at the end of this document for your convenience.

Direction
(Degrees)

Resistance
(Ohms)

Voltage
(V=5v, R=10k)
ADC Reading | Range Selection
N (0) | 33k | 3.84v | 20352 | 19600-20999
NNE (22.5) | 6.57k | 1.98v | 10512 | 9000-10799
NE (45) | 8.2k | 2.25v | 11952 | 10800-13999
ENE (67.5) | 891 | 0.41v | 2176 | 2000-2299
E (90) | 1k | 0.45v | 2416 | 2300-2999
ESE (112.5) | 688 | 0.32v | 1712 | 1000-1999
SE (135) | 2.2k | 0.90v | 4768 | 4000-4999
SSE (157.5) | 1.41k | 0.62v | 3264 | 3000-3999
S (180) | 3.9k | 1.40v | 7440 | 6600-8999
SSW (202.5) | 3.14k | 1.19v | 6336 | 5000-6599
SW (225) | 16k | 3.08v | 16336 | 15900-16999
WSW (247.5) | 14.12k | 2.93v | 15536 | 14000-15899
W (270) | 120k | 4.62v | 24464 | 24000-24999
WNW (292.5) | 42.12k | 4.04v | 21440 | 21000-21999
NW (315) | 64.9k | 4.78v | 22992 | 22000-23999
NNW (337.5) | 21.88k | 3.43v | 18208 | 17000-19599

Wind Speed

Wind speed is the rate of horizontally moving air past a fixed point, and measured by an anemometer. Some definitions for the weather app (on the Raspberry Pi):

Wind Speed – Current wind speed is the average wind speed recorded over a defined period, 3 seconds for example (i.e., the “LOOP” period).

Average Speed – An average of all wind speed-readings (i.e., LOOP readings) collected over a defined period, 5 minutes for example (i.e., the ARCHIVE period).

Peak Speed – A rolling value showing the highest wind speed recorded over a given interval (usually the ARCHIVE interval).

Wind Chill and Feels-Like Temperature

Wind Chill
Wind chill temperature only works for temperatures at or below 10°C (50°F) and wind speeds above 4.8kph (3.0 mph). The standard Wind Chill formula from Environment Canada (using °C and km/h; but the same formula converted to °F and MPH is used in the USA) is:

Twc = 13.12 + 0.6215Ta − 11.37v

+ 0.16 + 0.3965Tav

+ 0.16

Where:

Twc is the wind chill index, based on the Celsius temperature scale;

Ta is the air temperature in degrees Celsius; and

v is the wind speed at 10m (33 ft.) standard anemometer height, in kilometres per hour.

When the temperature is −20 °C (−4 °F) and the wind speed is 5 km/h (3.1 mph), the wind chill index is −24. If the temperature remains at −20 °C and the wind speed increases to 30 km/h (19 mph), the wind chill index falls to −33.

Feels-Like Temperature
A heat index (https://en.wikipedia.org/wiki/Heat_index) value is valid for temperatures at or over 27° Celsius.

There are many formulae devised to approximate the original tables by Steadman. Anderson et al (2013), NWS (2011), Jonson and Long (2004), and Schoen (2005) have lesser residuals in this order. The former two are a set of polynomials, but the third one is by a single formula with exponential functions.

The formula below approximates the heat index in degrees Fahrenheit, to within ±1.3 °F (0.7 °C). It is the result of a multivariate fit to a model of the human body. The temperature must be equal to or greater than 80 °F (27 °C) and relative humidity equal to or greater than 40%. This equation reproduces the above NOAA National Weather Service table (except the values at 90 °F (32 °C) and 45%-70% relative humidity vary unrounded by less than ±1, respectively). (WeeWX uses this one)

HI = c1 + c2T + c3R + c4 TR + c5T

2 + c6R

2 + c7T

2R + c8TR² + c9T

2R

2

Where:

HI = heat index (in degrees Fahrenheit)
T = ambient dry-bulb temperature (in degrees Fahrenheit)
R = relative humidity (percentage value between 0 and 100)
c 1 = − 42.379 | c 2 = 2.04901523 | c 3 = 10.14333127
c 4 = − 0.22475541 | c 5 = − 6.83783 × 10⁻³ | c 6 = − 5.481717 × 10⁻²
c 7 = 1.228 74 × 10⁻³ | c 8 = 8.5282 × 10⁻⁴ | c 9 = − 1.99 × 10⁻⁶

Temperature

The DS18B20 temperature sensor shows up on the Raspberry Pi with an address something like 28-0517c13642ff as noted in the setup instructions above. The sensor provides a value in centigrade.

The simple formula to convert between Fahrenheit (°F) and degrees Celsius (°C):

Tc = 9
/5 × (Tf − 32)
Tf = (⁵
/9) × Tc + 32

Where:
Tc is temperature in Celsius
Tf is temperature in Fahrenheit

WeeWX looks after all these conversions … see the documentation on the Standard web report.

Humidity

The humidity is measured inside the case containing the Pi, therefore this relative humidity (RH) reading is relative to the temperature inside the case (i.e., case_temp) and must be converted to a RH for the temperature outside (i.e., the outTemp). The following formulæ are used:

See: https://www.lenntech.com/calculators/humidity/relative-humidity.htm

# This humidity is measured inside the case,

# which is warmer than the ambient air. Therefore # it is converted to external humidity based upon # the case_temp and outTemp. First calculate the

# absolute moisture level in the air.

absMoisture = (humidity * 0.42 * math.exp(case_temp * 0.06235398)/10)

# Now calculate the humidity reading to the outside temperature humidity = (absMoisture * 10 / (0.42 * math.exp(outTemp * 0.06235398)))

Pressure

The current pressure is displayed in hectopascals (hPa). A trend of the changing pressure shows what has happened over the last 3 hours.

Rainfall

The rainfall amount accumulated over the LOOP period is tracked. Weather Underground displays:

- Rain – the accumulation of rain in the past 1 hr and the past 24 hrs
- Rate – the current rate of rainfall in mm/hr for the LOOP period

There are certain situations where a single random rain “tick” may occur:

- Certain gusts of strong wind could cause a random tick—if the “bucket” is not exactly level and when at rest on the high side a strong gust could knock it back;
- Melting frost or dew may accumulate enough to cause a random tick over time;
- An almost full “bucket” and a sudden gust of wind can also cause it to tick over.

The WeeWX driver therefore has a random tick detector to catch single ticks. The downside is that the first tick when it actually starts to rain will be ignored.

## Wunderground

The WeeWX software can share its reading with your own Weather Underground web page. Register your Personal Weather Station (PWS) at wunderground.com, where you will receive a station ID along with a password. Enter these into the weewx.conf file as directed here:

http://weewx.com/docs/usersguide.htm#[StdRESTful]

Wunderground registration detail example:

Your Station ID: | ABCDEFGxx
Your Station Key/Password: | abxycdij

Example WU PWS URL:

https://www.wunderground.com/personal-weather-station/dashboard?ID=IOTTAWA98

Once your PWS is setup you can use this WU URL in your [Station] section’s station_url setting.

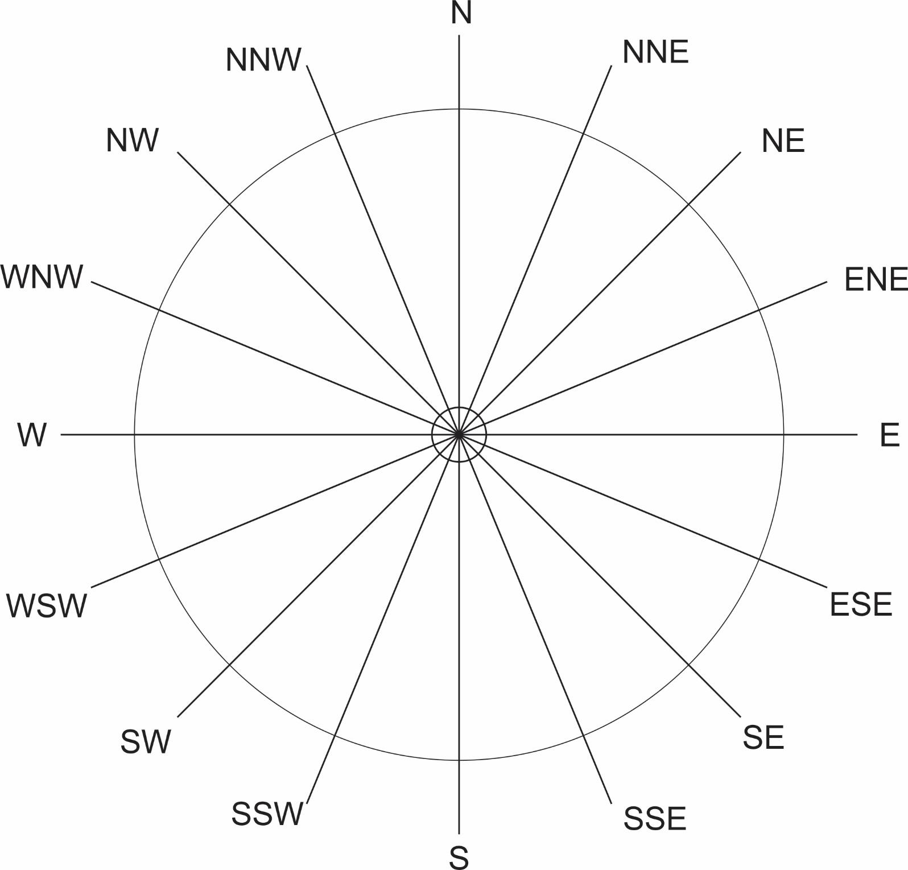
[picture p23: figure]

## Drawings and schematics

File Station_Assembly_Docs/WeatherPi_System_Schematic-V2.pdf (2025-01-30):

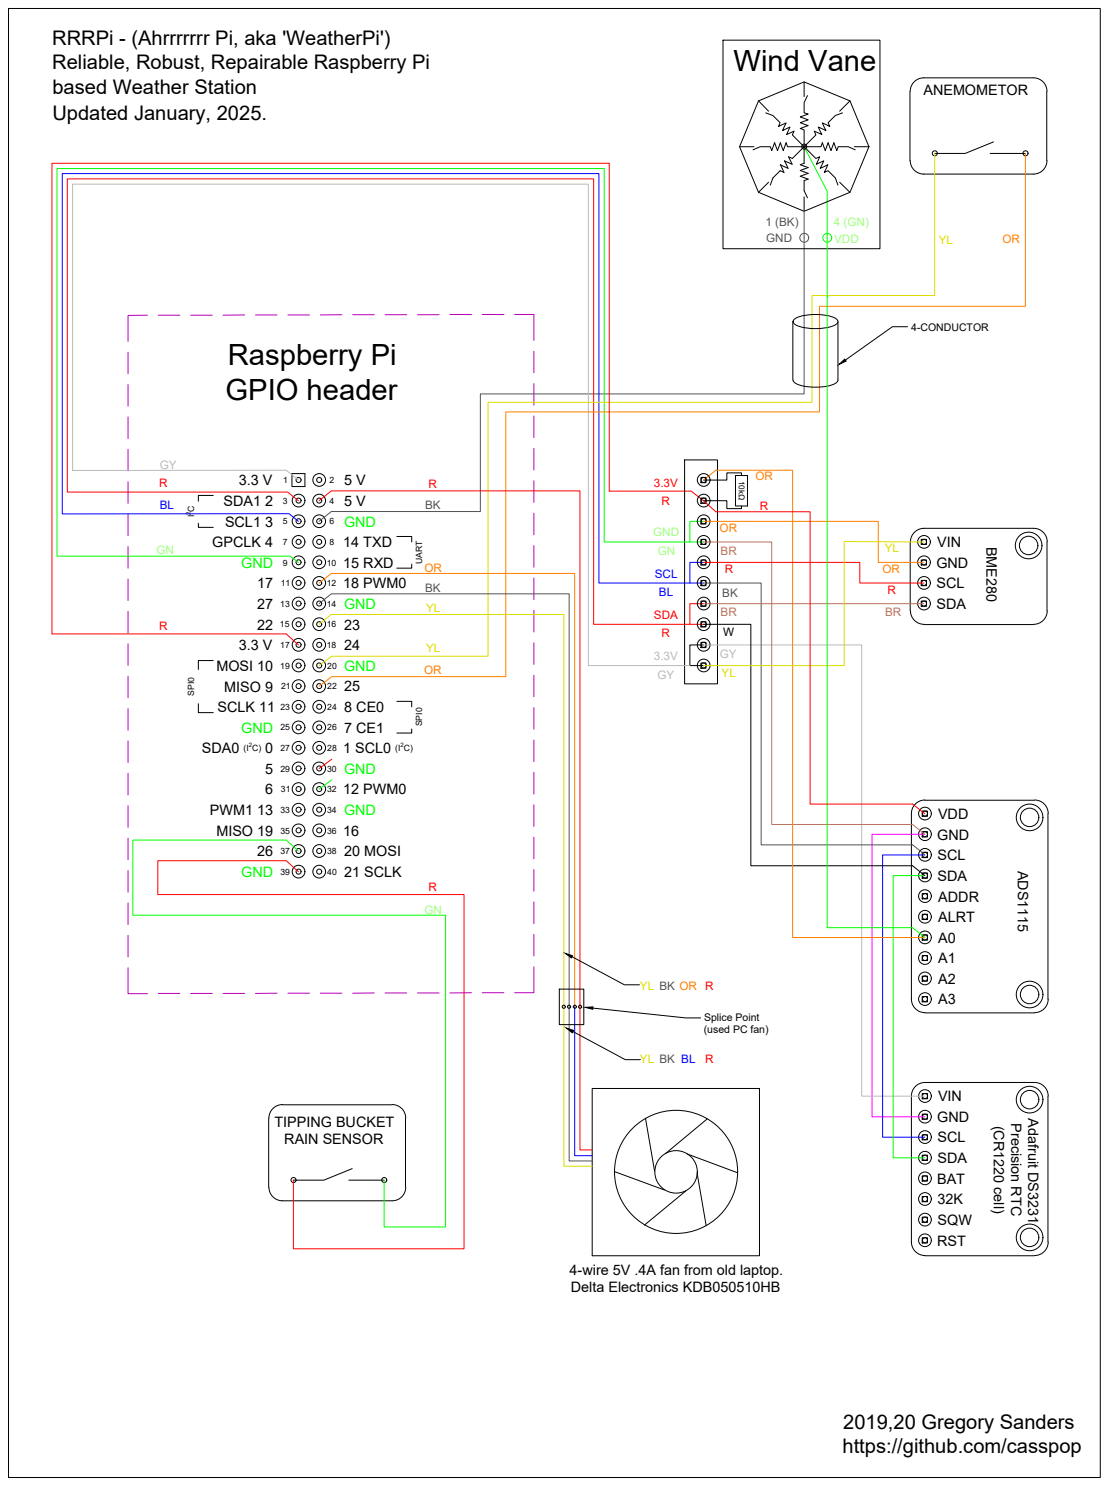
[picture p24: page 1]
3.3 V SDA1 2 SCL1 3 GPCLK 4; 3.3 V MOSI 10 MISO 9 SCLK 11; SDA0 (I2C) 0; PWM1 13 MISO 19; 14 TXD 15 RXD 18 PWM0; 8 CE0 7 CE1 1 SCL0 (I2C) GND; 12 PWM0; 20 MOSI; 21 SCLK UART; SPI0 SPI0 I2C; Raspberry Pi; GPIO header; Wind Vane; RST; Precision RTC Adafruit DS3231 (CR1220 cell); GN GND; TIPPING BUCKET RAIN SENSOR

RRRPi - (Ahrrrrrrr Pi, aka 'WeatherPi')
Reliable, Robust, Repairable Raspberry Pi
based Weather Station
Updated January, 2025.

R BK

BR BR

Splice Point
(used PC fan)

4-wire 5V .4A fan from old laptop.
Delta Electronics KDB050510HB

2019,20 Gregory Sanders
https://github.com/casspop

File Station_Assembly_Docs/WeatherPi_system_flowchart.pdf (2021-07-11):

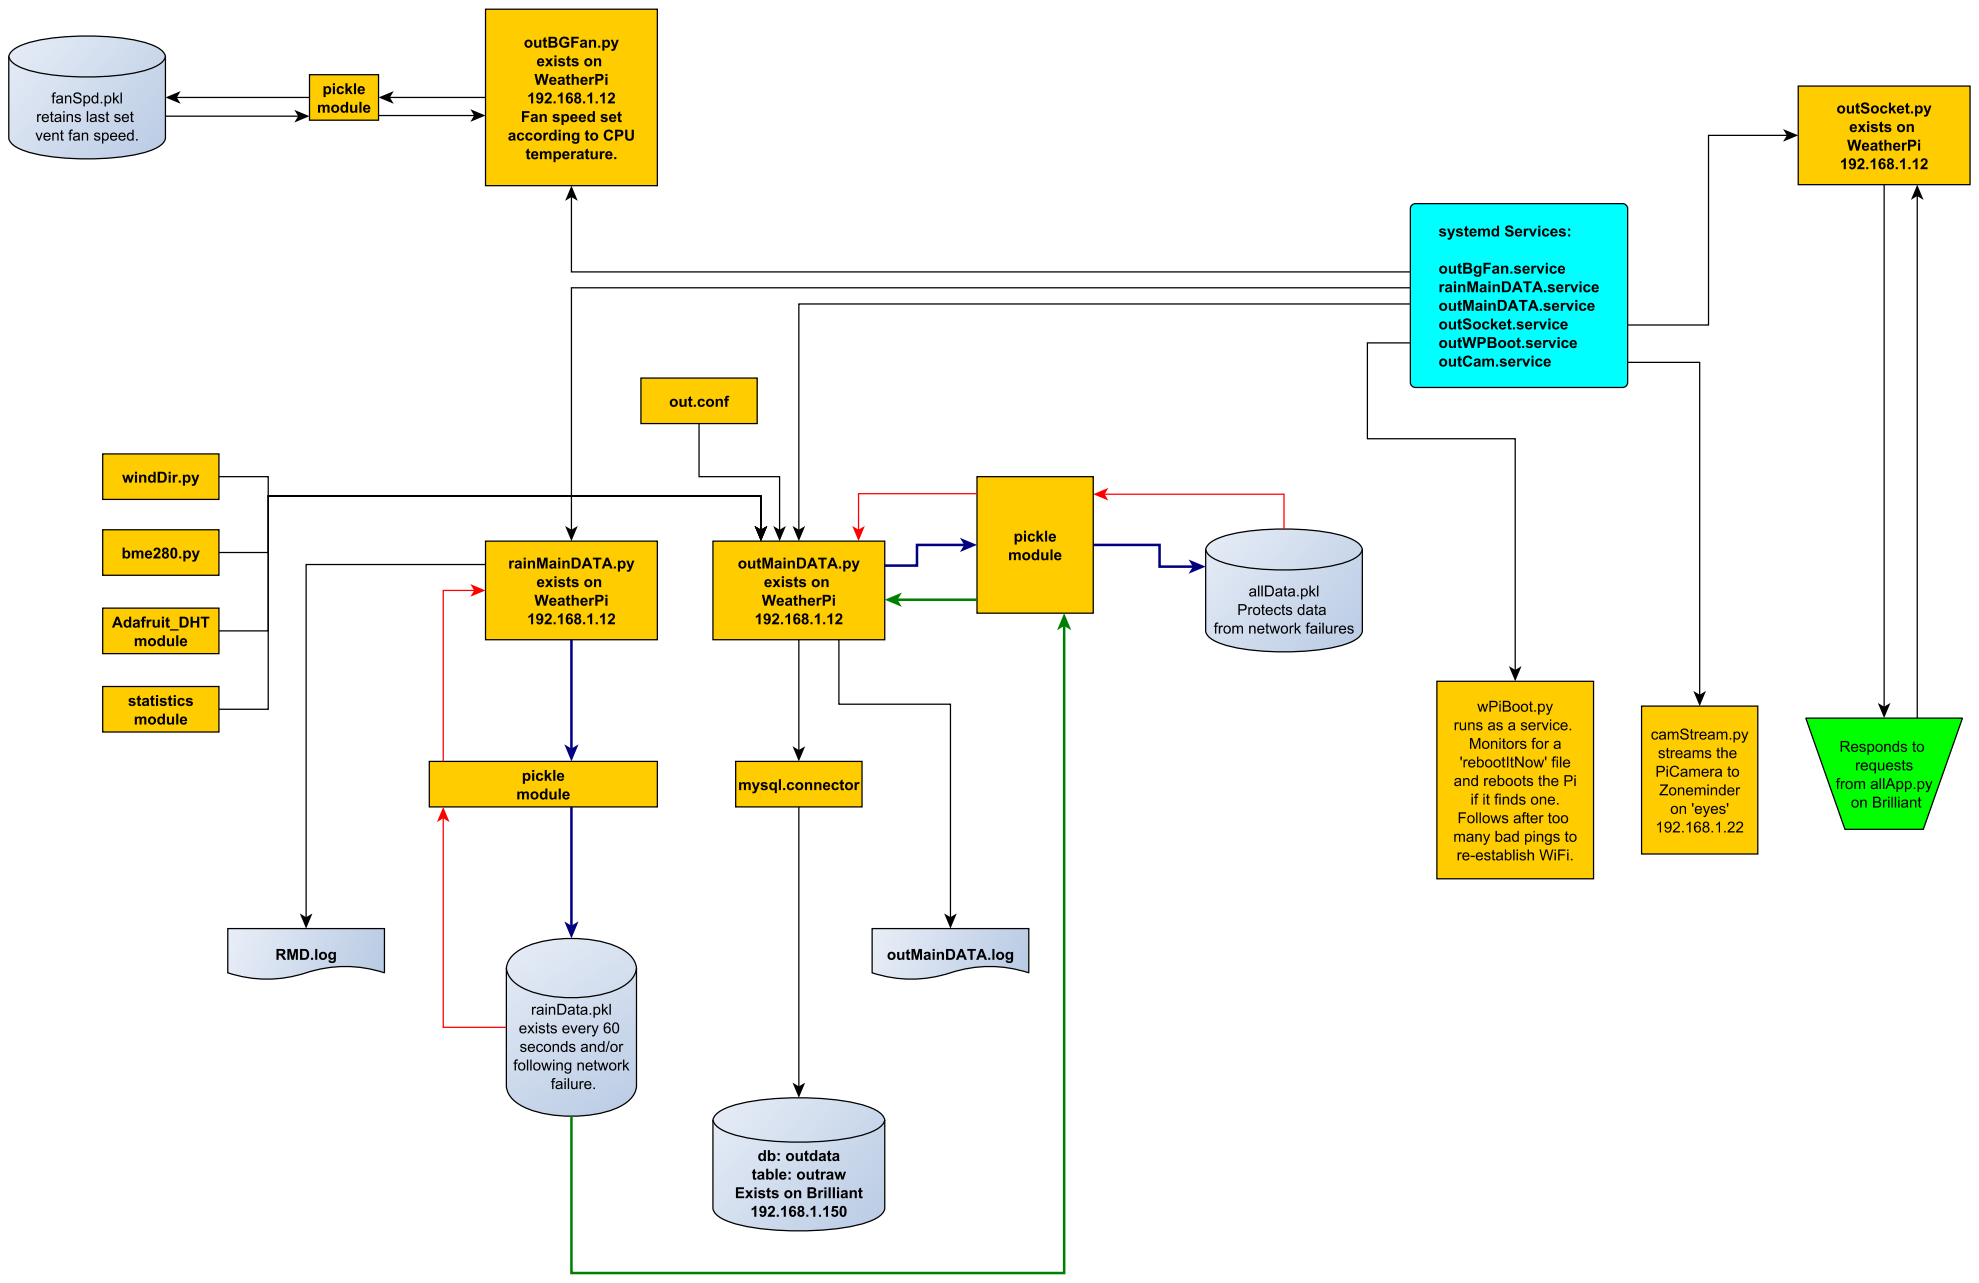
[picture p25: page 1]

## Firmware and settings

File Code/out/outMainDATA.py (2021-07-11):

#!/usr/bin/env python3
#
#   outMainDATA.py - A working file to build the data logging parts of outMain.py.

#     Copyright (c) 2019,2020 - Gregory Allen Sanders.

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
import datetime,time,argparse,bme280,os,subprocess,logging,signal,sys,statistics,mysql.connector,configparser,pickle,Adafruit_DHT
import windDir as wDirection
from time import sleep
import RPi.GPIO as GPIO
from mysql.connector import MySQLConnection, Error

DHT_SENSOR = Adafruit_DHT.DHT22
DHT_PIN = 24
wsPin = 16
rps = 0
kph = 0
mph = 0
rpulse = 0
timeVal = 0
rstart = 0
accResults = []
pklData = []
tableData = []
numBadPings = 0
pressure = 0
outTemp = 0
outHumidity = 0
extraHumid1 = 0 # rawHumidity
windSpeed = 0
winddir = 0
windGust = 0
windGustDir = 0
rainRate = 0
rain = 0
extraTemp1 = 0 # CPU temp
#
## DHT22 SENSOR DATA GRABBER FUNCTION
#
def dht22Data():
    humidity = None
    tempC = None
    while humidity == None or tempC == None:
        humidity, tempC = Adafruit_DHT.read_retry(DHT_SENSOR, DHT_PIN)
        time.sleep(3)
    return humidity, tempC
#    
##      Setup for Sensor Data Logging.  Each parameter gets logged for a minute
##      then we run some stats, and share the output of that with the next step.
#
def datagrabber():
    global timeVal
    start = time.time()
    accPress = []
    accTemp = []
    accHum = []
    accXhum = []
    accWspdK = []
    accWspdM = []
    accWdir = []
    accWdeg = []
    rain = 0
    rainRate = 0

    while time.time() - start < 57:                       ## The plan here is to run this for a minute,
                                                          ## then get the median values to return.
        GPIO.setmode(GPIO.BCM)                            ## THIS BEGINS WIND SPEED ACQUISITION
        GPIO.setup(wsPin, GPIO.IN, pull_up_down=GPIO.PUD_UP)
        GPIO.setwarnings(False)
        pstart = time.time()
        elapse = 0
        pulse = 0
        while elapse < 2:
            pRtn = GPIO.wait_for_edge(16, GPIO.FALLING,timeout=1000)
            if pRtn != None:
                pulse += 1
            elapse = time.time() - pstart
        rps = pulse/elapse
        kph = '{:.2f}'.format(rps * 2.40114125)
        mph = '{:.2f}'.format(rps * 1.492)
        extraHumid1 = 0                             ########  REMOVE THIS LINE WHEN YOU PURGE extraHumid1 "Raw Humidity" ######
        outTemp2,pressure = bme()                         ## ACQUIRE alternateTEMP,PRES
        outHumidity,outTemp = dht22Data()                 ## ACQUIRE humidity and temp from DHT22
        wdir,wdeg = wDirection.main()                     ## ACQUIRE wdir (string) and wdeg (float) FROM windDir.py
#                                                         ## ACQUIRE rain, rainRate from .pkl file (if exists)
#                                                         ##   0.011" of rain causes one bucket-tip (1 pulse)
        if os.path.exists(OMDHome + '/rainData.pkl'):     ## Check for .pkl file from rainMainDATA.py
            try:
                timeVal = time.time()
                rainData = [0,timeVal]                          ## Set rainData as an empty list in case loading the .pkl fails.
                rainData = pickle.load(open(OMDHome + '/rainData.pkl', 'rb'))
                logger.debug('rainData variable was populated from rainData.pkl: ' + str(rainData))
            except EOFError:
                logger.debug("Encountered an empty .pkl file.  Moving on without it.")
                rainData = [0,0]
            os.remove(OMDHome + '/rainData.pkl')          ## delete the .pkl file after reading it.
            if not os.path.exists(OMDHome + '/rainData.pkl'):
                logger.debug("rainData.pkl Pickle file erased.")
#                timeVal = time.time()                                       These two lines were added but I think it caused problems.
#                rainData = [[0,timeVal,timeVal,0]]                          ## Set rainData as an empty list in case loading the .pkl fails.
            logger.debug('The rainData list has ' + str(len(rainData)) + ' records in it at datagrabber().')
            tips = 0
            for row in rainData:
                tips = tips + row[0]
                timeVal = row[1]
            rain = rain + (tips * 0.011)                           ## rain in the last minute
            logger.debug('Calculated ' + str(rain) + ' inches from ' + str(tips) + ' tips from rainData.pkl.')
            # logger.info('The rainData list has ' + str(len(rainData)) + ' records in it.')
            bench1 = time.time() - timeVal
            # logger.info('It took ' + str(bench1) + ' seconds from last tick check to read the rainData.pkl file.')
            rainRate = (rain * 60)                          ## rain variable times 60 gives us rain per hour
        # else:
            #logger.info('rainData.pkl did not exist this time around.')
            
        accPress.append(pressure)
        accTemp.append(outTemp)
        accHum.append(outHumidity)
        accXhum.append(extraHumid1)
        accWspdK.append(float(kph))
        accWspdM.append(float(mph))
        accWdeg.append(wdeg)
        if argsOMD.debug:
            print(str(time.time() - start) + ': Wind Deg: ' + str(wdeg) + ' Wind Speed: ' + str(mph))
    loopTimer = time.time() - start
    logger.debug('time.time() - start = ' + str(loopTimer))
    pressure = statistics.median(accPress)                ## Get the middle value in the list of values
    outTemp = statistics.median(accTemp)                  ## accumulated over the last 60 seconds
    outHumidity = statistics.median(accHum)
    extraHumid1 = statistics.median(accXhum)
    windSpeed = statistics.median(accWspdM)
    windGust = max(accWspdM)
    if argsOMD.debug:
        print(accWspdM)
    winddir = statistics.median(accWdeg)
    wdirStr = wDirCvt(winddir)                            ## use the wDirCvt function to generate the string value for wind direction
#                                                         ## from the middle wind direction (in degrees) 
    logger.debug('outMainData.py datagrabber() has run and is returning values to mydb().')
    if rain > 0:
        logger.info('Reporting ' + str(rain) + ' inches of rain.')
    return pressure,outTemp,outHumidity,extraHumid1,windSpeed,winddir,wdirStr,rain,rainRate,timeVal,windGust
#
##
# 
def wDirCvt(wdegval):
    winddirS = "Not Connected"
    val = wdegval
    if val <= 11.25 or val == 0:
        val = val + 360
    if 348.76 <= val <= 371.25:
        winddirS = "N"
    if 11.26 <= val <= 33.75:
        winddirS = 'NNE'
    if 33.76 <= val <= 56.25:
        winddirS = 'NE'
    if 56.26 <= val <= 78.75:
        winddirS = 'ENE'
    if 78.76 <= val <= 101.25:
            winddirS = 'E'
    if 101.26 <= val <= 123.75:
            winddirS = 'ESE'
    if 123.76 <= val <= 146.25:
            winddirS = 'SE'
    if 146.26 <= val <= 168.75:
            winddirS = 'SSE'
    if 168.76 <= val <= 191.25:
            winddirS = 'S'
    if 191.26 <= val <= 213.75:
            winddirS = 'SSW'
    if 213.76 <= val <= 236.25:
            winddirS = 'SW'
    if 236.26 <= val <= 258.75:
            winddirS = 'WSW'
    if 258.76 <= val <= 281.25:
            winddirS = 'W'
    if 281.26 <= val <= 303.75:
            winddirS = 'WNW'
    if 303.76 <= val <= 326.25:
            winddirS = 'NW'
    if 326.26 <= val <= 348.75:
            winddirS = 'NNW'
    return winddirS
#
# A calculation to approximate the dewpoint when humidity is over 50%
# Td = T - ((100 - RH)/5.)
#   
#   THESE ARE THE FINAL VARIABLES WE WANT TO PASS TO THE DATABASE
#   
#   pressure
#   outTemp
#   outHumidity
#   extraHumid1 = rawHumidity
#   windSpeed
#   winddir
#   windGust
#   windGustDir
#   rainRate
#   rain
#   extraTemp1 = CPU temp
#   
#   I'm going to use the prefix 's_' to indicate a 'samples' list variable.  So 'outTemp' becomes 's_outTemp'.
#   's_outTemp' contains the list of values accumulated during this one-shot gathering episode.
#
## GRAB SENSOR DATA FROM THE BME280 MODULE
#
def bme():  #####  7/10/2021 - aDDED DHT22 SENSOR FOR TEMP/HUMIDITY.  LOOK FOR dht22Data() function.

    s_outTemp = []
    s_pressure = []
    # s_outHumidity = []
    # s_rawHumidity = []
    tstart = time.time()

    while time.time() - tstart < 2:
        tempC,pres = bme280.readBME280All()
        s_outTemp.append(tempC)
        s_pressure.append(pres)
        # s_outHumidity.append(humid)
        # s_rawHumidity.append(preHum)
    outTemp = statistics.mean(s_outTemp)
    pressure = statistics.mean(s_pressure)
    # outHumidity = statistics.mean(s_outHumidity)
    # extraHumid1 = statistics.mean(s_rawHumidity)

    # return outTemp,pressure,outHumidity,extraHumid1
    return outTemp,pressure
#
## START WRITE-TO-DATABASE FUNCTION
# Be aware that because we are using WiFi to connect to the network, we have to make arrangements in case
# the connection drops.  It happens.  So we are getting sensor data, putting it in a list, checking for a .pkl file
# which will exist if the connection test failed last time around, appending our new data to the data from that .pkl file,
# ping the SQL server machine, if good: write rows of data from our list and delete the .pkl file. If not good: dump the appended list to 
# the .pkl file (which overwrites it if it existed) and then swing back around to do it all again.
#
def mydb():
    global pklData,numBadPings
    # Get current values from all the sensors.
    pressure,outTemp,outHumidity,extraHumid1,windSpeed,winddir,wdirStr,rain,rainRate,timeVal,windGust = datagrabber()
    # Get the vent fan RPM from the pickle file.
    try:
        fan1 = pickle.load(open(OMDHome + '/fanSpd.pkl', 'rb'))
    except EOFError:
        logger.debug("Encountered an empty .pkl file.  Moving on without it.")
        fan1 = 0
        pass
    # Get the CPU temperature from the system.
    cpuT = cpuTemp()[1]
    # Now make sure all the variables are of the right type.  Take no chances.
    prs = float(pressure)
    otmp = float(outTemp)
    ohmd = float(outHumidity)
    xohmd = float(extraHumid1)
    wspd = float(windSpeed)
    wgust = float(windGust)
    wdir = float(winddir)
    wdirStr = wdirStr
    if rain > 0:
        rain = float(rain)
        logger.debug('inside mydb(), rain is: ' + str(rain))
    if rainRate > 0:
        rainRate = float(rainRate)
    dtNow = int(time.time())
    dataTable = [dtNow,prs,otmp,ohmd,wspd,wdir,wdirStr,xohmd,cpuT,fan1,rain,rainRate,wgust]  # Put all the readings into a list.
    if os.path.exists(OMDHome + '/allData.pkl'):            ## This .pkl file will exist if the upcoming ping test failed last time around.
        pklData = pickle.load(open(OMDHome + '/allData.pkl', 'rb'))
    pklData.append(dataTable)                               ## Merge the recent data with the .pkl file data just in case we are still offline
    logger.debug('dataTable was appended to pklData')
    DBhost=config.get('mySQL','Address')                    # get the mySQL login data from our config file.
    DBuser=config.get('mySQL','User')
    DBpasswd=config.get('mySQL','Password')
    DBdatabase=config.get('mySQL','Database')
    DBtable=config.get('mySQL','Table1')
    # Don't stop now . . . keep going!!!
    ## Check to see if we can ping the machine mySQL is running on
    pingRes = subprocess.call(['/bin/ping', '-c', '1', DBhost], stdout=subprocess.DEVNULL)  ## Ping test to make sure the SQL machine is there.
    logger.debug("Ping for server returned: " + str(pingRes))
    if pingRes == 0:                                        # We are connected.  Move ahead.  If not, don't do any of this stuff.
        if numBadPings > 0:
            logger.info("Connection to SQL server machine restored.")
        numBadPings = 0                                     # Prep the data, and send it to the SQL machine.
        for row in pklData:                                 # Normally there will only be one row. UNLESS the network was down, 
            dtNow = row[0]                                  # in which case there can be many.
            prs = row[1]
            otmp = row[2]
            ohmd = row[3]
            wspd = row[4]
            wdir = row[5]
            wdirStr = row[6]
            xohmd = row[7]
            cpuT = row[8]
            fan1 = row[9]
            rain = row[10]
            rainRate = row[11]
            wgust = row[12]
            try:
                # prepare the database connector 
                mydb = mysql.connector.connect(
                    host=DBhost,
                    user=DBuser,
                    passwd=DBpasswd,
                    database=DBdatabase
                )
                cursor = mydb.cursor()                      # Attempt a connection with the remote database. If it is not there, 
                cursor.execute("select database();")        # an exception will be logged and we will save our data for the 
                record = cursor.fetchone()                  # next go-round.
                logger.debug("Got the database: " + str(record))
                addRecord = ('INSERT INTO ' + DBdatabase + '.' + DBtable + '' \
                    ' (dateTime,pressure,outTemp,outHumidity,windSpeed,winddir,wdirStr,extraHumid1,cpuTemp,fan1,rain,rainRate,windGust)' \
                    ' VALUES (%s,%s,%s,%s,%s,%s,%s,%s,%s,%s,%s,%s,%s)')
                addData = (dtNow,prs,otmp,ohmd,wspd,wdir,wdirStr,xohmd,cpuT,fan1,rain,rainRate,wgust)
                logger.debug(addRecord %addData)
                cursor.execute(addRecord,addData)
                cursor.execute("SELECT * FROM " + DBdatabase + '.' + DBtable + " where id=(select max(id) from " + DBdatabase + '.' + DBtable + ")")
                record = cursor.fetchone()
                logger.debug('The last record contains: ' + str(record))
                mydb.commit()
                cursor.close()
                mydb.close()
                pklData = []                                ## RESET pklData to an empty list.
                if timeVal > 0:
                    elapsedTime = time.time() - timeVal
                    # logger.info('From last Rain tick check to writing the database record was ' + str(elapsedTime) + ' seconds.')
                if os.path.exists(OMDHome + '/allData.pkl'):
                    os.remove(OMDHome + '/allData.pkl')
                    logger.debug("allData.pkl Pickle file erased.")
            except Exception:
                logger.info('Unable to connect with mySQL database.  Details to follow: ', exc_info=True)
                pass
            funNStr = sys._getframe().f_code.co_name
            logger.debug("Finished the " + funNStr + " function")
    else:                                                           # We are NOT CONNECTED.  Save our readings to a .pkl file
        logger.info("Ping test for SQL server machine failed.")
        numBadPings += 1
        pickle.dump(pklData, open(OMDHome + '/allData.pkl', 'wb+'), pickle.HIGHEST_PROTOCOL)
        logger.debug("allData.pkl updated.")
        logger.info ("Number of bad pings is: " + str(numBadPings) + ".")
        if numBadPings >= 3:
            logger.info("Too many bad pings.  Setting up to reboot.")
            os.mknod(OMDHome + '/rebootItNow')
#
##  END OF WRITE-TO-DATABASE FUNCTION
#

#
## Grab the CPU temperature while you're at it.
#
def cpuTemp():
# Return CPU temperature in C and F
    ct = os.popen('vcgencmd measure_temp').readline()
    cpuRtn = ct.replace("temp=","").replace("'C\n","")
    cpuT1=float(cpuRtn)
    cpuT2=float(9/5 * cpuT1 + 32.00)
    return cpuT1,cpuT2
#
## = = = = = = = =  END OF WEATHER CODE - START OF ERROR HANDLING, LOGGING AND WRAPUP CODE  = = = = = = = = =
#
def SignalHandler(signal, frame):
        if signal == 2:
            sigStr = 'CTRL-C'
            logger.info('* * * ' + sigStr + ' caught. * * * ')
        print("SignalHandler invoked")
        logger.info("Cleaning up")
        GPIO.cleanup()
        logger.info("Shutting down gracefully")
        logger.debug("Wrote to log in SignalHandler")
        logger.info("Finished SignalHandler")
        logger.info("That's all folks.  Goodbye")
        logger.info(" - - - - outMainDATA.py DATA LOGGING STOPPED INTENTIONALLY - - - - ")
        sys.exit(0)

if __name__ == "__main__":
    #
    ## Arg parsing moved down here so we can use functions from this file as a module without conflicting the commandline arguments.
    #
    parserOMD = argparse.ArgumentParser()
    parserOMD.add_argument("-d", "--debug", help="Turn on debugging output to log file.", action="store_true")
    OMDHome = os.getcwd()
    logger = logging.getLogger(__name__)
    #
    config = configparser.RawConfigParser()
    config.read(OMDHome + '/out.conf')
    #
    argsOMD = parserOMD.parse_args()

    if argsOMD.debug:
        import traceback
        logging.basicConfig(filename=OMDHome + '/outMainDATA.log', format='[%(name)s]:%(levelname)s: %(message)s. - %(asctime)s', datefmt='%D %H:%M:%S', level=logging.DEBUG)
        logging.info("Debugging output enabled")
    else:
        logging.basicConfig(filename=OMDHome + '/outMainDATA.log', format='%(asctime)s - %(message)s', datefmt='%a, %d %b %Y %H:%M:%S', level=logging.INFO)
    #
    logger.info(" - - - - outMainDATA.py DATA LOGGING STARTED - - - - ")
    logger.info("  INITIAL CONFIGURATION COMPLETE  ")
    logger.info("'HOME' path is: " + OMDHome)
    #
    ## END Args parsing and logging setup.
    #
    import traceback
    try:
        signal.signal(signal.SIGINT, SignalHandler)  ## This one catches CTRL-C from the local keyboard
        signal.signal(signal.SIGTERM, SignalHandler) ## This one catches the Terminate signal from the system
        logger.debug(" Top of try")
        while True:
            mydb()
        pass

        logger.debug("Bottom of try")
#            logger.flush()
    except Exception:
        logger.info("Exception caught at bottom of try.", exc_info=True)
        error = traceback.print_exc()
        logger.info(error)
        logger.info("That's all folks.  Goodbye")
        logger.info(" - - - - outMainDATA.py DATA LOGGING STOPPED BY EXCEPTION - - - - ")

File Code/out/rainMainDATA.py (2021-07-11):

#!/usr/bin/env python3
#
#   rainMainDATA.py - do data logging of rainfall.

#     Copyright (c) 2019,2020 - Gregory Allen Sanders.

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

import time,os,logging,configparser,argparse,traceback,signal,sys,pickle,statistics
from time import sleep
import RPi.GPIO as GPIO

#
## - - - - - RAIN CODE BELOW HERE - - - - These lines log to RMD.log
#
GPIO.setmode(GPIO.BCM)
GPIO.setup(24, GPIO.IN, pull_up_down=GPIO.PUD_DOWN)
GPIO.setup(12, GPIO.IN, pull_up_down=GPIO.PUD_UP)
GPIO.setwarnings(False)
rpulse = 0
#rstart = time.time()
gppulse = 0
gpstart = 0
timeVal = 0            
#                      # ('r' is for 'rain'.  rpulse is "rain pulse", rstart is "rain start", get it?)
##  STARTING HERE WE ARE GETTING THE BUCKET TIP DATA READY FOR outMainDATA TO PICK IT UP AS IT GOES BY.
##  WE COLLECT IT, STACK IT UP FOR 60 SECONDS, AND LEAVE IT LAYING IN THE WORKING FOLDER IN A .pkl FILE.
#
iterList = []
rainList = []
#
#
def gotPulse(channel):
    # 0.011" of rain causes one bucket-tip (1 pulse)
    global gppulse,gpstart
    gppulse += 1
    gpstart = time.time()
    logger.info('Got a pulse.')
    return gppulse,gpstart

GPIO.add_event_detect(12, GPIO.FALLING, callback=gotPulse, bouncetime=200)

def main():
    global rpulse,gppulse,gpstart
    digVal = GPIO.input(24)
#    if digVal == 0:
#        startCount = time.time()
#        endCount = startCount + 3600
    checkit = GPIO.input(12)
    # logger.info('Input pin 12 is :' + (str(checkit)))
    try:
        # logger.info('Top of main() try.')
#        while time.time() < endCount:
        iterList = []
        rainList = []
        cntCycle = time.time()
        # logger.info(int(cntCycle))
# Part I
        while time.time() - cntCycle < 58:
            timeVal = time.time()
            digVal = GPIO.input(24)
            if gppulse >= 1:
                rpulse = gppulse
            else:
                rpulse = 0
                gpstart=time.time()
            # if rpulse > 0:
                # logger.info('Appending ' + str(rpulse) + ' pulses to interList.')
            iterList = [rpulse,timeVal,gpstart,digVal]
            gppulse = 0
            gpstart = 0
            rainList.append(iterList)                                               ## add the most recent data to rainList.
            sleep(1)
        else:                                                                       ## After the 60 seconds (give or take) passes, do part II.
#  Part II
            if os.path.exists(RMDHome + '/rainData.pkl'):                           ## Check for .pkl file. One would exist if there had been network issues.
                rainDataList = pickle.load(open(RMDHome + '/rainData.pkl', 'rb'))   ## Read the .pkl file contents into rainDataList.
                logger.debug('rainDataList is '+ str(len(rainDataList)) + " records long.") 
                # logger.debug('rainDataList variable was populated from rainData.pkl: ')
                os.remove(RMDHome + '/rainData.pkl')                                ## delete the .pkl file after reading it.
                if not os.path.exists(RMDHome + '/rainData.pkl'):
                    logger.info("rainData.pkl Pickle file erased.")
                for row in rainList:                                                ## Append the contents of the new rainList to rainDataList.
                    rainDataList.append(row)
                logger.debug('Appended rainList to rainDataList.')
            else:
                logger.debug('Saving rainList to rainData.pkl.')
                rainDataList = rainList                                             ## if there wasn't a .pkl file, make rainDataList from rainList and move on.
        pickle.dump(rainDataList, open(RMDHome + '/rainData.pkl', 'wb+'), pickle.HIGHEST_PROTOCOL) ## Save rainDataList to the .pkl file for outMainDATA.py.
        logger.debug('rainDataList is '+ str(len(rainDataList)) + " records long and was was saved in rainData.pkl.")
        rainList = []
        rainDataList = []
        pass

    except Exception:
        logger.info("Exception caught at bottom of try.", exc_info=True)
        pass
#

#
## = = = = = = = =  END OF RAIN CODE - START OF ERROR HANDLING, LOGGING AND WRAPUP CODE  = = = = = = = = =
#

def SignalHandler(signal, frame):
    if signal == 2:
        sigStr = 'CTRL-C'
        logger.info('* * * ' + sigStr + ' caught. * * * ')
    GPIO.cleanup()
    print("SignalHandler invoked")
    logger.info("Shutting down gracefully")
    logger.debug("Wrote to log in SignalHandler")
    logger.info("That's all folks.  Goodbye")
    logger.info(" - - - - rainMainDATA.py LOGGING STOPPED INTENTIONALLY - - - - ")
    sys.exit(0)

if __name__ == "__main__":
    #
    ## Arg parsing moved down here so we can use functions from this file as a module without conflicting the commandline arguments.
    #
    parserRMD = argparse.ArgumentParser()
    group = parserRMD.add_mutually_exclusive_group()
    group.add_argument('-d', '--debug', help="Turn on debugging output to log file.", action="store_true")
    group.add_argument('-f', '--func', help="Call the specified function.", action="store_true")
    RMDHome = os.getcwd()
    logger = logging.getLogger(__name__)
    #
    config = configparser.RawConfigParser()
    config.read(RMDHome + '/out.conf')
    #
    argsRMD = parserRMD.parse_args()

    if argsRMD.debug:
        logging.basicConfig(filename=RMDHome + '/RMD.log', format='[%(name)s]:%(levelname)s: %(message)s. - %(asctime)s', datefmt='%D %H:%M:%S', level=logging.DEBUG)
        logging.info("Debugging output enabled")
    else:
        logging.basicConfig(filename=RMDHome + '/RMD.log', format='%(asctime)s - %(message)s', datefmt='%a, %d %b %Y %H:%M:%S', level=logging.INFO)
    #
    logger.info(" - - - - rainMainDATA.py LOGGING STARTED - - - - ")
    logger.info("  INITIAL CONFIGURATION COMPLETE  ")
    logger.debug("'HOME' path is: " + RMDHome)
    #
    ## END Args parsing and logging setup.
    #
    signal.signal(signal.SIGINT, SignalHandler)  ## This one catches CTRL-C from the local keyboard
    signal.signal(signal.SIGTERM, SignalHandler) ## This one catches the Terminate signal from the system    
    try:
        print(" Top of try")
        while True:
            main()
        pass
#                print("Bottom of try")
    except Exception:
        logger.info("Exception caught at bottom of try.", exc_info=True)
        GPIO.cleanup()
        error = traceback.print_exc()
        logger.info(error)
        logger.info("That's all folks.  Goodbye")
        logger.info(" - - - - rainMainDATA.py LOGGING STOPPED BY EXCEPTION - - - - ")

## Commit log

2020-02-22 Correction to system schematic
2020-03-28 General updates
    [weewxDatabaseStructure.xlsx]
2020-03-28 Fan docs started
2020-03-28 Update Ventilation Fan Notes.md
2020-04-04 edits to readme.md
    [PiBoxFanMountV4.skp, PiBoxFanMountV4.stl, ShroudV4b.skp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]
2020-04-04 Added Fan mount files
    [FanMountV4.skp, FanMountV4.stl, PiBoxFanMountV4.skp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]
2020-04-07 Main Power Supply Docs
2020-04-07 RPi 40 pin diagram
2020-04-28 Added 5V fan resource
2020-05-02 Station_Parts_List.xlsx
    All the parts you need to build this station. List started Saturday May 2, 2020.
    [Station_Parts_List.xlsx]
2020-05-02 Final Parts List
    [Station_Parts_List.xlsx]
2020-05-02 Final Parts List Spreadsheet
    [Station_Parts_List.xlsx]
2020-05-14 edits to parts lists
    [Station_Parts_List.xlsx]
2020-05-14 added Pi 4 model .stl
    [Pi 4 Model.stl]
2020-05-18 PDF'ed the Station parts list
    [Station_Parts_List.xlsx]
2020-08-05 renamed sensor mount files
    [BME280_holder.skp, BME280_holder.stl]
2020-09-14 Power supply notes in README.md
2020-09-14 notes on Power Supply
2020-09-16 correcting Schematic link
2026-08-09 Aug 2026 freshening of the repo. Current running files.
    My intention is to freshen this repo and keep it fresh. These files are what's running here on my WeatherPi. They may or may not be suitable for your purposes, but they are, at least, informative.
2026-08-09 Aug 2026 update to currently running files.

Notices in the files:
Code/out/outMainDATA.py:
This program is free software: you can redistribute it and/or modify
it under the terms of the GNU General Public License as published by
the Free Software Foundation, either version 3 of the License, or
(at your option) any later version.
